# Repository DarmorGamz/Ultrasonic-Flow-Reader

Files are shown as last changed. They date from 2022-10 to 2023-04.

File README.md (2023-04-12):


<!-- PROJECT LOGO -->
<br />
<div align="center">
  <a href="https://github.com/DarmorGamz/Ultrasonic-Flow-Reader">
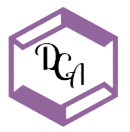
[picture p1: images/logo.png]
    
  </a>
<h3 align="center">Ultrasonic Flow Reader</h3>

  <p align="center">
    The Ultra Sonic Flow Reader is a non-invasive, innovative solution that enables real-time water flow monitoring in pipes using ultrasonic waves. Designed for homeowners, residential and industrial building owners, and property managers, this device helps reduce installation costs and risks associated with traditional inline installations, while promoting water conservation and potential cost savings.
    <br />
    <br />
    <a href="https://github.com/DarmorGamz/Ultrasonic-Flow-Reader">View Demo</a>
    ·
    <a href="https://github.com/DarmorGamz/Ultrasonic-Flow-Reader/issues">Report Bug</a>
    ·
    <a href="https://github.com/DarmorGamz/Ultrasonic-Flow-Reader/issues">Request Feature</a>
  </p>
</div>

### Built With

[][C-url]

[][HTML-url] [][CSS3-url] [][JavaScript-url]

[][PHP-url] [][MYSQL-url] [][Linux-url] [][AWS-url]

<!-- ABSTRACT -->
## ABSTRACT
The Ultra Sonic Flow Reader is a non-invasive solution designed to measure the flow of water in pipes using ultrasonic waves, eliminating the need for costly and time-consuming inline installation by licensed plumbers. Targeting homeowners, residential and industrial building owners, and property managers, this innovative device empowers users to monitor their water usage in real time, leading to potential cost savings and improved water conservation. The project employs ultrasonic transducers, a SAMD20 microcontroller, Winc1500 for WiFi, ENC28J60 for Ethernet, and leverages AWS for RDS, EC2, and Route53. The firmware is developed using Embedded C, with a PHP backend, and a frontend designed using HTML, CSS, and JavaScript. The Ultra Sonic Flow Reader is expected to minimize the need for hiring plumbers and reduce the risk of potential damage associated with traditional inline installations. The project's final demonstration is scheduled for April 13, 2023, showcasing a user-friendly and efficient solution for real-time water usage monitoring.

<!-- INTRODUCTION -->
## INTRODUCTION

#### Enhancing Water Usage Monitoring
The Ultra Sonic Flow Reader project was conceived with the primary goal of addressing a pressing need in the field of water monitoring and management. Traditional methods for measuring water flow in pipes typically require invasive installations and the assistance of licensed plumbers. This process can be both expensive and time-consuming, posing significant challenges for homeowners, residential and industrial building owners, and property managers who are looking to monitor their water usage in real time. As water scarcity becomes an increasingly critical global issue, there is a growing demand for innovative solutions that facilitate efficient water management and conservation.

#### Target Users and Applications
The project's scope encompasses the design and development of a non-invasive, cost-effective, and user-friendly device capable of real-time water usage monitoring. The Ultra Sonic Flow Reader employs advanced technologies such as ultrasonic transducers, a SAMD20 microcontroller, Winc1500 for WiFi, and ENC28J60 for Ethernet. In addition, it leverages Amazon Web Services (AWS) for database management (RDS), cloud computing (EC2), and domain name management (Route53). The device's firmware is developed using Embedded C, while the backend is built using PHP, and the frontend is designed with HTML, CSS, and JavaScript.

#### Project Development Phases
The approach taken to the project involved extensive research, planning, and execution of various design phases, including hardware and software development, integration, and testing. The interdisciplinary team, consisting of Darren Morrison, Austin Cormier, and Carter Glynn, collaborated closely under the supervision of Professors Hameed Al-Aubodah, Hamood-ur Rehman, Jane Carr, and Mehrdad Hajivandi to bring the project to fruition.

#### Challenges of Traditional Inline Installations
The Ultra Sonic Flow Reader project has been designed with a focus on simplicity, adaptability, and ease of use. Recognizing the diverse needs of homeowners, property managers, and residential and industrial building owners, the team has strived to create a solution that caters to a wide range of applications. The device's non-invasive nature ensures that it can be installed without causing disruptions to existing infrastructure or requiring specialized skills.
Throughout the project, the team has been guided by a set of core principles, including innovation, collaboration, and a commitment to addressing real-world challenges. These principles have driven the development process and informed key decisions, such as the selection of appropriate hardware components, software design, and integration strategies. Additionally, the team has placed a strong emphasis on testing and validation, ensuring that the Ultra Sonic Flow Reader consistently delivers accurate and reliable results.
As the project progresses towards its final demonstration, scheduled for April 13, 2023, the team remains dedicated to refining the Ultra Sonic Flow Reader and addressing any outstanding issues or limitations. The team acknowledges that further research and development efforts will be essential in enhancing the device's applicability to a wider range of pipe sizes and optimizing its power supply requirements. By addressing these challenges, the Ultra Sonic Flow Reader will be better positioned to meet the needs of its target users and make a positive impact on water management and conservation efforts.
In summary, the Ultra Sonic Flow Reader project represents a significant advancement in the field of water monitoring and management. By offering a non-invasive, cost-effective, and user-friendly solution for real-time water usage monitoring, the device has the potential to transform the way homeowners, building owners, and property managers approach water conservation. This report serves to document the project's journey from conception to completion, providing a comprehensive account of the team's research, development, and validation efforts.
This report details the problem statement, which outlines the challenges faced by traditional inline water flow monitoring systems and the need for a non-invasive alternative. The development process, including the project proposal, changes and decisions made throughout the project, and challenges encountered in implementation, is thoroughly discussed. Furthermore, the report presents the testing procedures and results, including Sprint tests, Product Validation tests, and an assessment of whether all user needs and requirements have been met. To support the report, relevant research materials, schematics, flowcharts, source code, and other documentation are included in the appendices.

#### Problem Statement
The Ultra Sonic Flow Reader project aims to revolutionize water monitoring by providing a solution that eliminates the need for hiring plumbers and reduces the risk of potential damage associated with traditional inline installations. By offering real-time water usage monitoring, the device empowers users to make informed decisions about their water consumption, leading to potential cost savings and improved water conservation efforts.

#### Report Structure
This report is organized into several sections, each focusing on a different aspect of the project. Following the introduction, the report details the problem statement, project development process, testing procedures and results, and any remaining limitations or challenges. The appendices provide additional documentation and materials to support the main body of the report.

<!-- INTRODUCTION -->
## DISCUSSION
The development of the Ultra Sonic Flow Reader project can be broken down into several key phases, each contributing to the overall success of the project. In this section, we discuss the progression of the project from proposal to completion, highlighting the changes and decisions made, challenges faced during implementation, and the various tests conducted.

#### Project Proposal and Initial Development
The project proposal was the foundation for the Ultra Sonic Flow Reader, outlining the primary objectives, expected outcomes, and proposed timeline. The team performed extensive research on existing flow measurement methods, identifying the limitations and drawbacks of traditional inline installations. This analysis informed the decision to pursue a non-invasive solution using ultrasonic waves for flow measurement.
Initial development focused on selecting appropriate hardware components, such as the ultrasonic transducers and SAMD20 microcontroller, and designing the basic hardware structure. The team also began work on the firmware using Embedded C and the backend using PHP, laying the groundwork for further development.

#### Iterative Development and Integration
Throughout the project, the team adopted an iterative development process, allowing for continuous improvements and adjustments. Hardware and software components were developed in parallel, with regular integration and testing to ensure compatibility and functionality.
Several changes were made during the development process, including the addition of Winc1500 for WiFi connectivity, ENC28J60 for Ethernet support, and the utilization of AWS for cloud-based services. These changes were made to enhance the device's usability and align it with modern IoT-based solutions.

#### Challenges and Implementation
The team encountered various challenges during the implementation phase. These included limited funding, time constraints, and complexities in debugging and hardware design. To overcome these challenges, the team members worked collaboratively, leveraging their individual skills and expertise to find solutions.
One of the key challenges was ensuring accurate flow measurement across various pipe sizes and materials. The team focused on refining the ultrasonic transducer placement and signal processing algorithms to achieve reliable results. Furthermore, optimizing power consumption was a priority, and the team worked on designing an energy-efficient system that minimizes the need for additional power sources.

#### Testing and Results
The Ultra Sonic Flow Reader underwent a series of tests to ensure its functionality, accuracy, and reliability. These tests included User Information Handling, API testing, Hardware Event Handling, and Hardware Timers testing. Each test was designed to evaluate specific aspects of the device's performance and identify areas for improvement.
The results of these tests showed that the Ultra Sonic Flow Reader met most user needs and requirements, delivering accurate flow measurements and a responsive user interface. However, some limitations were identified, such as the need for a more modular sensor PCB mount and optimization of the power supply.

#### References to Appendices
Throughout the report, references are made to the appendices, which contain supplementary material such as research materials, schematics, flowcharts, and source code. These documents provide a more in-depth understanding of the Ultra Sonic Flow Reader's design and development process and can be used to replicate the project and verify its results.

<!-- RECOMMENDATION -->
## RECOMMENDATION
Based on the findings and conclusions of the Ultra Sonic Flow Reader project, the following recommendations are provided to guide future research, development, and commercialization efforts.

#### Wider Pipe Size Compatibility
The current design supports only 1-inch pipes, limiting the applicability of the device. Future research should focus on developing a more modular sensor PCB mount, enabling compatibility with a broader range of pipe sizes to cater to various residential and industrial applications.

#### Power Supply Optimization
The power supply requirements of the current design demand a minimum of 12V for the sensor PCB to function. Optimizing the power supply to support lower voltage levels could enhance the device's energy efficiency, minimize the need for additional power sources, and potentially extend its battery life.

#### Enhanced User Interface
While the existing user interface is functional, it could benefit from further refinement to improve user experience. Future iterations should consider incorporating more advanced data visualization features, customizable alerts, and a mobile application for increased accessibility.

#### Market Research and Consumer Feedback
Conduct market research and solicit feedback from potential end-users to gain insights into user needs, preferences, and potential use cases. This information can inform future design decisions and contribute to the development of a more market-ready product.

#### Compliance with Regulatory Standards
As the project moves towards commercialization, it is crucial to research safety requirements, electronic stamping, and other relevant industry standards to ensure the Ultra Sonic Flow Reader complies with all necessary regulations.

#### Cost Reduction and Production Efficiency
To improve profit margins and streamline production, consider bulk purchasing of components, outsourcing board soldering, and adopting lean manufacturing practices.

#### Long-term Testing and Reliability
Further long-term testing should be conducted to assess the device's durability, performance consistency, and overall reliability under various environmental conditions and extended usage periods.
By addressing these recommendations, the Ultra Sonic Flow Reader can evolve into a more refined and market-ready product, better positioned to meet the needs of its target users and contribute significantly to water conservation efforts.

<!-- APPENDICES -->
## APPENDICES
#### Schematics
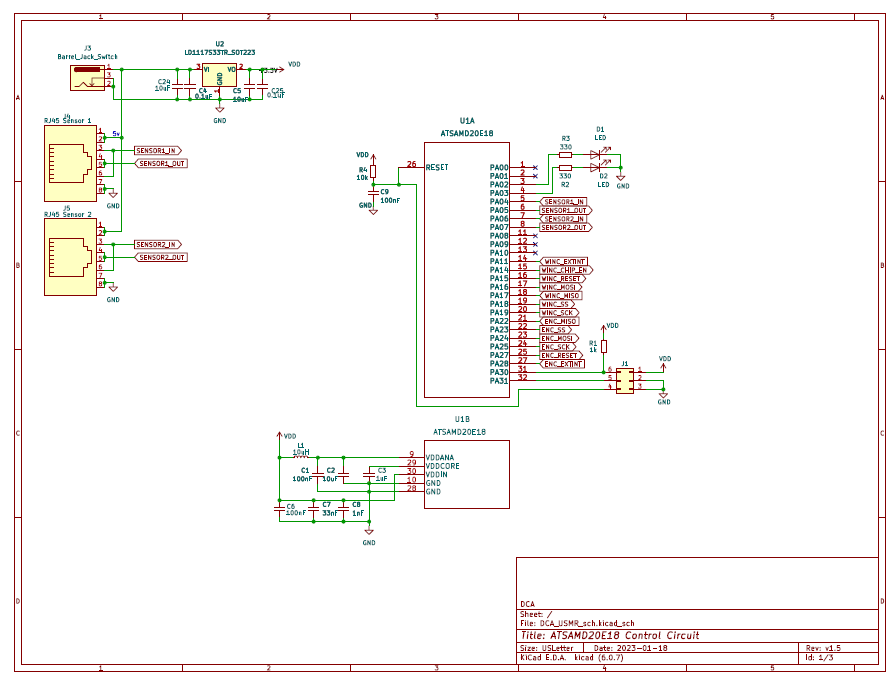
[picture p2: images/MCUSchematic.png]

Fig. 1.	MCU - Atmel SAMD20 circuit.

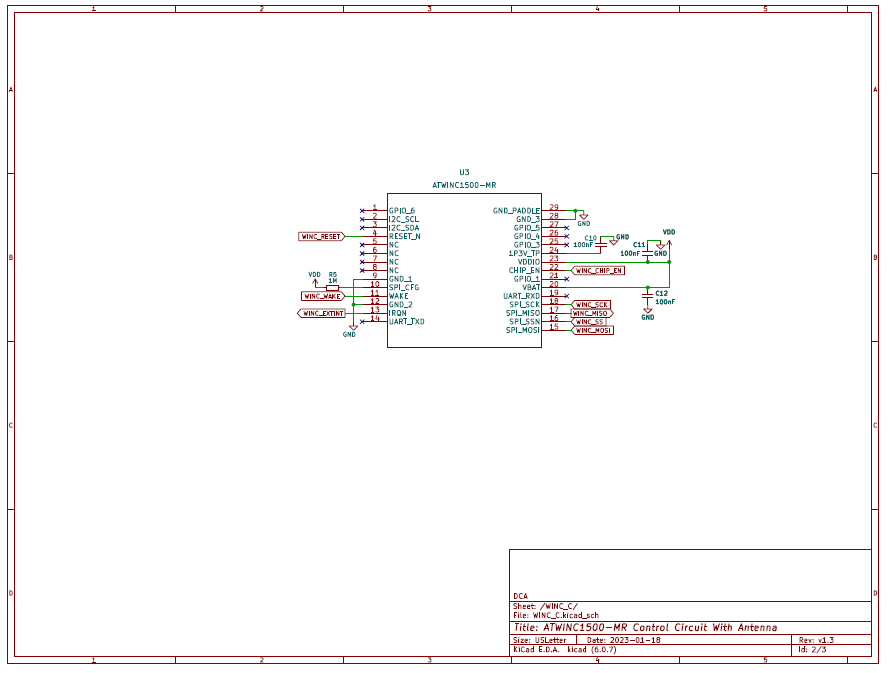
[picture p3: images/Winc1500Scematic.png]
 
Fig. 2.	Wifi – Winc1500 circuit.

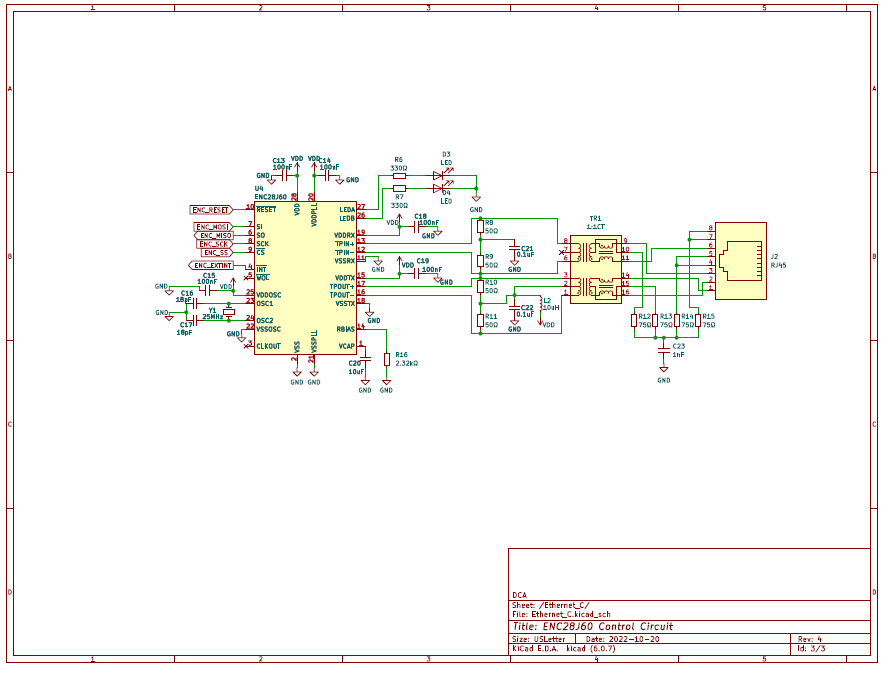
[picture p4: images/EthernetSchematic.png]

Fig. 3.	Ethernet – ENC28J60 circuit.

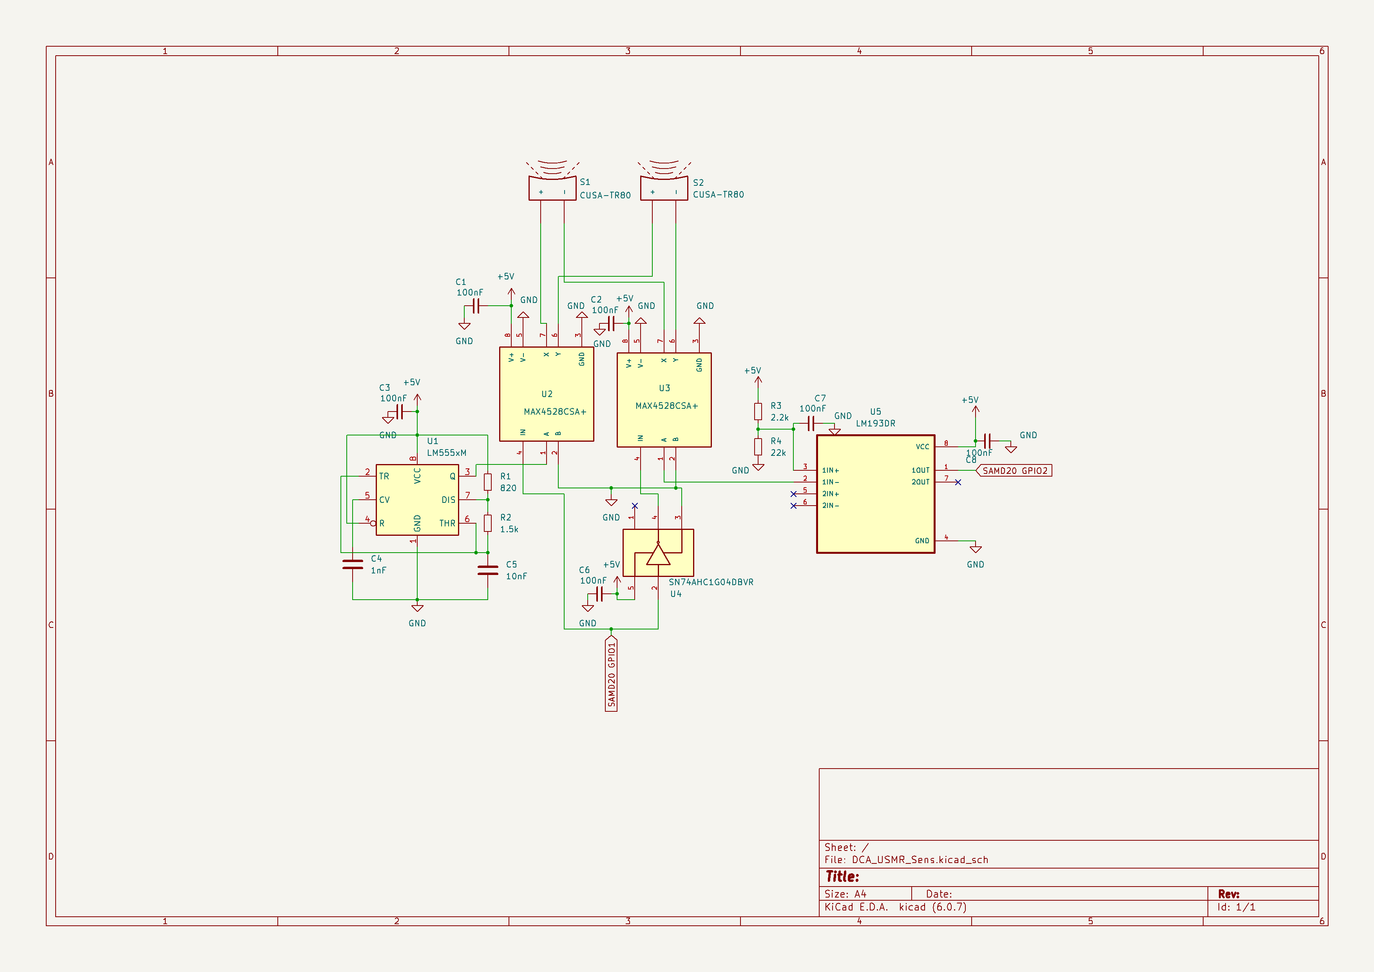
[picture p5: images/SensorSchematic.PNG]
 
Fig. 4.	Sensor – Ultra sonic flow reader circuit.   

#### Flowcharts
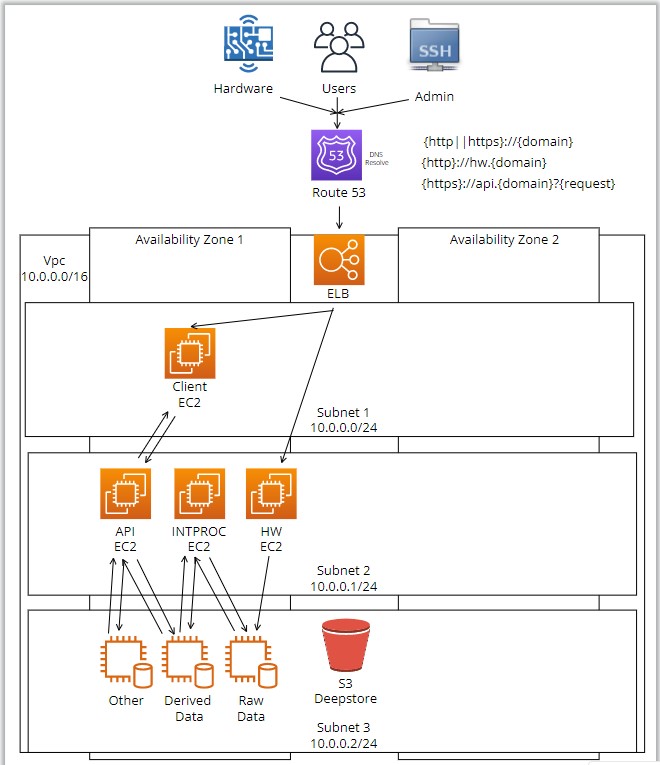
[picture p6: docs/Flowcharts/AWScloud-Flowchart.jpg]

Fig. 5. Cloud – AWS design flowchart

<!-- GETTING STARTED -->
## Getting Started

This is an example of how you may give instructions on setting up your project locally.
To get a local copy up and running follow these simple example steps.

### Prerequisites

### Installation

<p align="right">(<a href="#readme-top">back to top</a>)</p>

<!-- CONTRIBUTING -->
## Contributing

Contributions are what make the open source community such an amazing place to learn, inspire, and create. Any contributions you make are **greatly appreciated**.

If you have a suggestion that would make this better, please fork the repo and create a pull request. You can also simply open an issue with the tag "enhancement".
Don't forget to give the project a star! Thanks again!

1. Fork the Project
2. Create your Feature Branch (`git checkout -b feature/AmazingFeature`)
3. Commit your Changes (`git commit -m 'Add some AmazingFeature'`)
4. Push to the Branch (`git push origin feature/AmazingFeature`)
5. Open a Pull Request

<p align="right">(<a href="#readme-top">back to top</a>)</p>

<!-- LICENSE -->
## License

Distributed under the Eyedro Green Solutions License. See `LICENSE.txt` for more information.

<p align="right">(<a href="#readme-top">back to top</a>)</p>

<!-- CONTACT -->
## Contact

Darren Morrison - darren09@live.ca  
Austin Cormier - austin14cormier@gmail.com   
Carter Glynn - carter.glynn14@gmail.com  

Project Link: [https://github.com/DarmorGamz/Ultrasonic-Flow-Reader](https://github.com/DarmorGamz/Ultrasonic-Flow-Reader)

<p align="right">(<a href="#readme-top">back to top</a>)</p>

<!-- ACKNOWLEDGMENTS -->
## Acknowledgments
We are deeply grateful to the following individuals for their invaluable contributions, guidance, and support during the development of the Ultra Sonic Flow Reader project:   

#### Dr. Hameed Al-Aubodah, PhD
*For his expertise in electrical theory (DC, AC, Transmission lines) and digital design, and for being an inspiring role model in the engineering field.*

#### Dr. Hamood-Ur Rehman, PhD
*For sharing essential software and programming knowledge, ensuring elegant, readable, and maintainable code, and for setting high expectations that contributed to the project's success.*

#### Dr. Mehrdad Hajivandi, PhD P.Eng
*For his guidance in mathematics and advanced thinking principles crucial to the project's development.*

#### Jane Carr
*For her expertise in testing, debugging, verification, and documentation, which played a significant role in the project's completion.*   
<br />
We also extend our appreciation to Eyedro Green Solutions for their generous funding, access to lab equipment, and invaluable mentorship throughout the project. Special thanks to:   

#### Trevor Orton, CEO
*For his guidance in cloud computing, backend development, and writing and maintaining quality code.*

#### Nick Gamble, CFO
*For sharing his expertise in embedded software, embedded systems, networking, and data analysis.*

#### Jeff Conley
*For his dedication to hardware design, product specifications, circuit design, PCB assembly, and document review.*  

<p align="right">(<a href="#readme-top">back to top</a>)</p>

<!-- REFERENCES -->
## References

T. Dean, "Sonar," Brown University, [Online]. Available: https://cs.brown.edu/people/tdean/courses/cs148/02/sonar.html.  
D. Russell, "The Doppler Effect," Kettering University, [Online]. Available: https://web.archive.org/web/20071119085900/http://www.kettering.edu/~drussell/Demos/doppler/doppler.html.  
University of Bristol, "Time-of-Flight Mass Spectrometry," [Online]. Available: https://web.archive.org/web/20120310184539/http://www.chm.bris.ac.uk/ms/theory/tof-massspec.html.  
J. Steensgaard, "Bootstrapped low-voltage analog switches," in 1999 IEEE International Symposium on Circuits and Systems (ISCAS), Orlando, FL, USA, 1999, pp. 29-32, vol.2, doi: 10.1109/ISCAS.1999.780611.  
Microchip Technology Inc., "SAMD20 Family Datasheet," [Online]. Available: https://ww1.microchip.com/downloads/en/DeviceDoc/SAM_D20_Family_Datasheet_DS60001504C.pdf.  
Microchip Technology Inc., "ENC28J60 Stand-Alone Ethernet Controller with SPI Interface," [Online]. Available: https://ww1.microchip.com/downloads/aemDocuments/documents/OTH/ProductDocuments/DataSheets/39662e.pdf. 
Microchip Technology Inc., "ATWINC15x0-MR210xB IEEE 802.11 b/g/n SmartConnect IoT Module," [Online]. Available: https://ww1.microchip.com/downloads/aemDocuments/documents/WSG/ProductDocuments/DataSheets/ATWINC15x0-MR210xB-IEEE-802.11-b-g-n-SmartConnect-IoT-Module-DS70005304E.p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.  
Amazon Web Services, "Amazon EC2 User Guide," [Online]. Available: https://docs.aws.amazon.com/AWSEC2/latest/UserGuide/concepts.html.  
Amazon Web Services, "Amazon RDS User Guide," [Online]. Available: https://docs.aws.amazon.com/AmazonRDS/latest/UserGuide/Welcome.html.  

<p align="right">(<a href="#readme-top">back to top</a>)</p>

<!-- MARKDOWN LINKS & IMAGES -->
<!-- https://www.markdownguide.org/basic-syntax/#reference-style-links -->
[contributors-shield]: https://img.shields.io/github/contributors/DarmorGamz/Ultrasonic-Flow-Reader.svg?style=for-the-badge
[contributors-url]: https://github.com/DarmorGamz/Ultrasonic-Flow-Reader/graphs/contributors
[forks-shield]: https://img.shields.io/github/forks/DarmorGamz/Ultrasonic-Flow-Reader.svg?style=for-the-badge
[forks-url]: https://github.com/DarmorGamz/Ultrasonic-Flow-Reader/network/members
[stars-shield]: https://img.shields.io/github/stars/DarmorGamz/Ultrasonic-Flow-Reader.svg?style=for-the-badge
[stars-url]: https://github.com/DarmorGamz/Ultrasonic-Flow-Reader/stargazers
[issues-shield]: https://img.shields.io/github/issues/DarmorGamz/Ultrasonic-Flow-Reader.svg?style=for-the-badge
[issues-url]: https://github.com/DarmorGamz/Ultrasonic-Flow-Reader/issues
[license-shield]: https://img.shields.io/github/license/DarmorGamz/Ultrasonic-Flow-Reader.svg?style=for-the-badge
[license-url]: https://github.com/DarmorGamz/Ultrasonic-Flow-Reader/blob/master/LICENSE.txt
[linkedin-shield]: https://img.shields.io/badge/-LinkedIn-black.svg?style=for-the-badge&logo=linkedin&colorB=555
[linkedin-url]: https://linkedin.com/in/darren--morrison

[C.com]: https://img.shields.io/badge/c-%2300599C.svg?style=for-the-badge&logo=c&logoColor=white
[C-url]: https://www.cprogramming.com
[PHP.com]: https://img.shields.io/badge/php-%23777BB4.svg?style=for-the-badge&logo=php&logoColor=white
[PHP-url]: https://www.php.net/
[MYSQL.com]: https://img.shields.io/badge/mysql-%2300f.svg?style=for-the-badge&logo=mysql&logoColor=white
[MYSQL-url]: https://www.mysql.com/
[HTML.com]: https://img.shields.io/badge/html5-%23E34F26.svg?style=for-the-badge&logo=html5&logoColor=white
[HTML-url]: https://www.w3.org/html/#:~:text=W3C%20HTML&text=https%3A%2F%2Fhtml.spec.whatwg,is%20the%20current%20HTML%20standard.
[CSS3.com]: https://img.shields.io/badge/css3-%231572B6.svg?style=for-the-badge&logo=css3&logoColor=white
[CSS3-url]: https://www.css3.com/
[JavaScript.com]: https://img.shields.io/badge/javascript-%23323330.svg?style=for-the-badge&logo=javascript&logoColor=%23F7DF1E
[JavaScript-url]: https://www.javascript.com/

[Linux.com]: https://img.shields.io/badge/Linux-FCC624?style=for-the-badge&logo=linux&logoColor=black
[Linux-url]: https://aws.amazon.com/amazon-linux-2/

[AWS.com]: https://img.shields.io/badge/AWS-%23FF9900.svg?style=for-the-badge&logo=amazon-aws&logoColor=white
[AWS-url]: https://aws.amazon.com/

[PHPStorm.com]: https://img.shields.io/badge/phpstorm-143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
[PHPStorm-url]: https://www.jetbrains.com/phpstorm/

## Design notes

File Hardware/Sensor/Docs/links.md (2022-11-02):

# LINKS

## Understanding Ultrasonic Sensors
https://www.sonotec.eu/fileadmin/user_upload/business_units/1-non-invasive-fluid-monitoring/expertise/flow-meters-for-process-monitoring/wp-flow-meters-for-process-m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 

https://www.ti.com/lit/an/slaa907d/slaa907d.pdf?ts=1665290222945

https://www.maxbotix.com/articles/how-ultrasonic-sensors-work.htm

## Transducer Selection
https://www.soundwatertech.com/news/how-to-select-the-best-ultrasonic-transducer-for-your-flowmeter-application

https://www.electronics-tutorials.ws/io/io_1.html

https://webench.ti.com/webench5/TDC/index.html?origin=pf_panel&app=flowHead

## Sensor Design
https://www.nxp.com/docs/en/reference-manual/DRM138.pdf

https://www.analog.com/en/design-center/reference-designs/circuits-from-the-lab/cn0343.html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

https://media.digikey.com/pdf/Data%20Sheets/Adafruit%20PDFs/4007_Web.pdf

https://media.digikey.com/pdf/Data%20Sheets/Adafruit%20PDFs/3942_Web.pdf

https://invensense.tdk.com/wp-content/uploads/2021/01/DS-000331-CH101-v1.4.pdf

https://www.maxbotix.com/documents/LV-MaxSonar-EZ_Datasheet.pdf

https://www.youtube.com/watch?v=e_cyxoqvWe8

https://www.youtube.com/watch?v=z4uxC7ISd-c

## Signal Processing
https://starfishmedical.com/blog/pros-cons-two-popular-ultrasound-signal-processing-techniques/

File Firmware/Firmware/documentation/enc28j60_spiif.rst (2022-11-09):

Microchip ENC28J60 Ethernet Controlloer
=======================================

The ENC28J60 is a stand-alone Ethernet controller
with an industry standard Serial Peripheral Interface
(SPI). It is designed to serve as an Ethernet network
interface for any controller equipped with SPI.

The ENC28J60 meets all of the IEEE 802.3 specifications.
It incorporates a number of packet filtering
schemes to limit incoming packets. It also provides an
internal DMA module for fast data throughput and hardware
assisted checksum calculation, which is used in
various network protocols. Communication with the
host controller is implemented via an interrupt pin and
the SPI, with clock rates of up to 20 MHz. Two
dedicated pins are used for LED link and network
activity indication.

Features
--------
* An SPI interface that serves as a communication channel between the host
  controller and the ENC28J60.
* Control registers which are used to control and monitor the ENC28J60.
* A dual port RAM buffer for received and transmitted data packets.
* An arbiter to control the access to the RAM buffer when requests are made
  from DMA, transmit and receive blocks.
* The bus interface that interprets data and commands received via the SPI
  interface.
* The MAC (Medium Access Control) module that implements IEEE 802.3 compliant
  MAC logic.
* The PHY (Physical Layer) module that encodes and decodes the analog data that
  is present on the twisted-pair interface.

Support
-------
[Home]: http://www.microchip.com/ENC28J60

Knows issues and workarounds
----------------------------
Currently The AVR SPI driver will not init the MOSI and SCK pin.
The Application and Example for TCPIP Lite Stack should modified after
import project into IDE(Atmel Stdio 7 or IAR).
The workaroud is put below code into driver_init.c->system_init() function:
MOSI_set_dir(PORT_DIR_OUT);
SCK_set_dir(PORT_DIR_OUT);
The MOSI and SCK keyword in above function maybe different with projects.
Please change them according the atmel_start_pins.h

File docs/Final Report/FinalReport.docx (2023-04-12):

# Ultra Sonic Flow Reader

# Senior Capstone Final Report

# Submitted by:

Darren Morrison

Austin Cormier

Carter Glynn

CET/EET Third Year

Under the Mentorship of

Dr. Hameed Al-Aubodah, PhD.

Program Coordinator

Dr. Hamood-Ur Rehman, PhD

Professor

Dr. Mehrdad Hajivandi, PhD, P.Eng.

Professor

Jane Carr

Professor

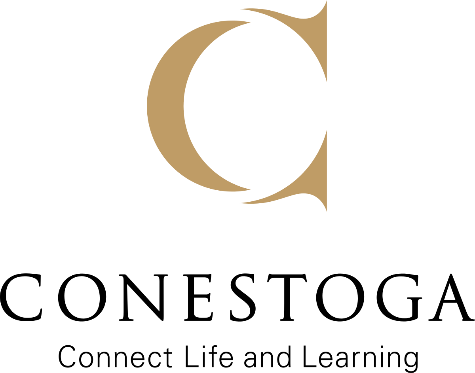
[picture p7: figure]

Computer Engineering Technology Department

Conestoga College Institute of Engineering & Technology, Cambridge

April, 2023

Ultra Sonic Flow Reader

Darren Morrison, Austin Cormier, Carter Glynn
Dept. Engineering and Technology
Conestoga College
Cambridge, Canada

Abstract—The Ultra Sonic Flow Reader is a non-invasive solution designed to measure the flow of water in pipes using ultrasonic waves, eliminating the need for costly and time-consuming inline installation by licensed plumbers. Targeting homeowners, residential and industrial building owners, and property managers, this innovative device empowers users to monitor their water usage in real time, leading to potential cost savings and improved water conservation. The project employs ultrasonic transducers, a SAMD20 microcontroller, Winc1500 for WiFi, ENC28J60 for Ethernet, and leverages AWS for RDS, EC2, and Route53. The firmware is developed using Embedded C, with a PHP backend, and a frontend designed using HTML, CSS, and JavaScript. The Ultra Sonic Flow Reader is expected to minimize the need for hiring plumbers and reduce the risk of potential damage associated with traditional inline installations. The project's final demonstration is scheduled for April 13, 2023, showcasing a user-friendly and efficient solution for real-time water usage monitoring.

Keywords—Ultrasonic flow measurement, Non-invasive flow monitoring, Water conservation, Real-time water usage, Internet of Things (IoT), Smart water management

##### Table of Contents

A) Enhancing Water Usage Monitoring
B) Target Users and Applications
C) Project Development Phases
D) Challenges of Traditional Inline Installations
E) Problem Statement
F) Report Structure
A) Project Proposal and Initial Development
B) Iterative Development and Integration
C) Challenges and Implementation
D) Testing and Results
E) References to Appendices
1. CONCLUSIONS
2. RECOMMENDATIONS
A) Wider Pipe Size Compatibility
B) Power Supply Optimization
C) Enhanced User Interface
D) Market Research and Consumer Feedback
E) Compliance with Regulatory Standards
F) Cost Reduction and Production Efficiency
G) Long-term Testing and Reliability
3. APPENDICES
A) SCHEMATICS

Fig 1) MCU - Atmel SAMD20 circuit

Fig 2) Wi-Fi – Winc1500 circuit

Fig 3) Ethernet – ENC28J60 circuit

Fig 4) Sensor – Ultra sonic flow reader circuit

B) FLOWCHARTS

Fig 5) Cloud – AWS design flowchart

Fig 6) Hardware – MCU component block diagram

Fig 7) Firmware – Embedded logic loop

Fig 8) Firmware - Embedded Clock Initialization

Fig 9) Firmware – Embedded Peripheral Initialization

4. ACKNOWLEDGMENTS
5. REFERENCES

# 1. Introduction

## A. Enhancing Water Usage Monitoring

The Ultra Sonic Flow Reader project was conceived with the primary goal of addressing a pressing need in the field of water monitoring and management. Traditional methods for measuring water flow in pipes typically require invasive installations and the assistance of licensed plumbers. This process can be both expensive and time-consuming, posing significant challenges for homeowners, residential and industrial building owners, and property managers who are looking to monitor their water usage in real time. As water scarcity becomes an increasingly critical global issue, there is a growing demand for innovative solutions that facilitate efficient water management and conservation.

## B. Target Users and Applications

The project's scope encompasses the design and development of a non-invasive, cost-effective, and user-friendly device capable of real-time water usage monitoring. The Ultra Sonic Flow Reader employs advanced technologies such as ultrasonic transducers, a SAMD20 microcontroller, Winc1500 for WiFi, and ENC28J60 for Ethernet. In addition, it leverages Amazon Web Services (AWS) for database management (RDS), cloud computing (EC2), and domain name management (Route53). The device's firmware is developed using Embedded C, while the backend is built using PHP, and the frontend is designed with HTML, CSS, and JavaScript.

## C. Project Development Phases

The approach taken to the project involved extensive research, planning, and execution of various design phases, including hardware and software development, integration, and testing. The interdisciplinary team, consisting of Darren Morrison, Austin Cormier, and Carter Glynn, collaborated closely under the supervision of Professors Hameed Al-Aubodah, Hamood-ur Rehman, Jane Carr, and Mehrdad Hajivandi to bring the project to fruition.

## D. Challenges of Traditional Inline Installations

The Ultra Sonic Flow Reader project has been designed with a focus on simplicity, adaptability, and ease of use. Recognizing the diverse needs of homeowners, property managers, and residential and industrial building owners, the team has strived to create a solution that caters to a wide range of applications. The device's non-invasive nature ensures that it can be installed without causing disruptions to existing infrastructure or requiring specialized skills.

Throughout the project, the team has been guided by a set of core principles, including innovation, collaboration, and a commitment to addressing real-world challenges. These principles have driven the development process and informed key decisions, such as the selection of appropriate hardware components, software design, and integration strategies. Additionally, the team has placed a strong emphasis on testing and validation, ensuring that the Ultra Sonic Flow Reader consistently delivers accurate and reliable results.

As the project progresses towards its final demonstration, scheduled for April 13, 2023, the team remains dedicated to refining the Ultra Sonic Flow Reader and addressing any outstanding issues or limitations. The team acknowledges that further research and development efforts will be essential in enhancing the device's applicability to a wider range of pipe sizes and optimizing its power supply requirements. By addressing these challenges, the Ultra Sonic Flow Reader will be better positioned to meet the needs of its target users and make a positive impact on water management and conservation efforts.

In summary, the Ultra Sonic Flow Reader project represents a significant advancement in the field of water monitoring and management. By offering a non-invasive, cost-effective, and user-friendly solution for real-time water usage monitoring, the device has the potential to transform the way homeowners, building owners, and property managers approach water conservation. This report serves to document the project's journey from conception to completion, providing a comprehensive account of the team's research, development, and validation efforts.

This report details the problem statement, which outlines the challenges faced by traditional inline water flow monitoring systems and the need for a non-invasive alternative. The development process, including the project proposal, changes and decisions made throughout the project, and challenges encountered in implementation, is thoroughly discussed. Furthermore, the report presents the testing procedures and results, including Sprint tests, Product Validation tests, and an assessment of whether all user needs and requirements have been met. To support the report, relevant research materials, schematics, flowcharts, source code, and other documentation are included in the appendices.

## E. Problem Statement

The Ultra Sonic Flow Reader project aims to revolutionize water monitoring by providing a solution that eliminates the need for hiring plumbers and reduces the risk of potential damage associated with traditional inline installations. By offering real-time water usage monitoring, the device empowers users to make informed decisions about their water consumption, leading to potential cost savings and improved water conservation efforts.

## F. Report Structure

This report is organized into several sections, each focusing on a different aspect of the project. Following the introduction, the report details the problem statement, project development process, testing procedures and results, and any remaining limitations or challenges. The appendices provide additional documentation and materials to support the main body of the report.

# 2. Discussion

The development of the Ultra Sonic Flow Reader project can be broken down into several key phases, each contributing to the overall success of the project. In this section, we discuss the progression of the project from proposal to completion, highlighting the changes and decisions made, challenges faced during implementation, and the various tests conducted.

## A. Project Proposal and Initial Development

The project proposal was the foundation for the Ultra Sonic Flow Reader, outlining the primary objectives, expected outcomes, and proposed timeline. The team performed extensive research on existing flow measurement methods, identifying the limitations and drawbacks of traditional inline installations. This analysis informed the decision to pursue a non-invasive solution using ultrasonic waves for flow measurement.

Initial development focused on selecting appropriate hardware components, such as the ultrasonic transducers and SAMD20 microcontroller, and designing the basic hardware structure. The team also began work on the firmware using Embedded C and the backend using PHP, laying the groundwork for further development.

## B. Iterative Development and Integration

Throughout the project, the team adopted an iterative development process, allowing for continuous improvements and adjustments. Hardware and software components were developed in parallel, with regular integration and testing to ensure compatibility and functionality.

Several changes were made during the development process, including the addition of Winc1500 for WiFi connectivity, ENC28J60 for Ethernet support, and the utilization of AWS for cloud-based services. These changes were made to enhance the device's usability and align it with modern IoT-based solutions.

## C. Challenges and Implementation

The team encountered various challenges during the implementation phase. These included limited funding, time constraints, and complexities in debugging and hardware design. To overcome these challenges, the team members worked collaboratively, leveraging their individual skills and expertise to find solutions.

One of the key challenges was ensuring accurate flow measurement across various pipe sizes and materials. The team focused on refining the ultrasonic transducer placement and signal processing algorithms to achieve reliable results. Furthermore, optimizing power consumption was a priority, and the team worked on designing an energy-efficient system that minimizes the need for additional power sources.

## D. Testing and Results

The Ultra Sonic Flow Reader underwent a series of tests to ensure its functionality, accuracy, and reliability. These tests included User Information Handling, API testing, Hardware Event Handling, and Hardware Timers testing. Each test was designed to evaluate specific aspects of the device's performance and identify areas for improvement.

The results of these tests showed that the Ultra Sonic Flow Reader met most user needs and requirements, delivering accurate flow measurements and a responsive user interface. However, some limitations were identified, such as the need for a more modular sensor PCB mount and optimization of the power supply.

## E. References to Appendices

Throughout the report, references are made to the appendices, which contain supplementary material such as research materials, schematics, flowcharts, and source code. These documents provide a more in-depth understanding of the Ultra Sonic Flow Reader's design and development process and can be used to replicate the project and verify its results.

# 3. Conclussions

The Ultra Sonic Flow Reader project has successfully demonstrated its potential as a non-invasive, cost-effective, and user-friendly solution for real-time water usage monitoring in residential and industrial settings. By utilizing cutting-edge technologies, such as ultrasonic transducers, SAMD20 microcontroller, and cloud-based services, the team has developed a reliable and efficient system capable of addressing the challenges associated with traditional inline installations.

Throughout the development process, the team faced various obstacles, including limited funding, time constraints, and complexities in debugging and hardware design. Despite these challenges, the team members were able to work collaboratively and leverage their individual skills to exceed the expected work hours and successfully deliver a working prototype.

The testing and validation phase provided valuable insights into the Ultra Sonic Flow Reader's performance, revealing that the device met the majority of user needs and requirements. However, certain limitations were identified, such as the need for a more modular sensor PCB mount and optimization of the power supply. Addressing these limitations in future research will be crucial in enhancing the device's applicability to a wider range of pipe sizes and further optimizing its performance.

As the project moves towards potential commercialization, considerations should be made for bulk purchasing of components, outsourcing board soldering, and ensuring compliance with safety requirements and electronic stamping regulations. By addressing these aspects, the Ultra Sonic Flow Reader will be better positioned for wider market adoption and increased impact on water management and conservation efforts.

In conclusion, the Ultra Sonic Flow Reader has showcased a promising solution for real-time water usage monitoring, with the potential to lead to substantial cost savings and improved water conservation for homeowners, building owners, and property managers. Further research and development efforts will be essential in refining the product and overcoming the existing limitations, ultimately paving the way for a more sustainable and efficient approach to water management.

# 4. Recommendations

Based on the findings and conclusions of the Ultra Sonic Flow Reader project, the following recommendations are provided to guide future research, development, and commercialization efforts

## A. Wider Pipe Size Compatibility

The current design supports only 1-inch pipes, limiting the applicability of the device. Future research should focus on developing a more modular sensor PCB mount, enabling compatibility with a broader range of pipe sizes to cater to various residential and industrial applications.

## B. Power Supply Optimization

The power supply requirements of the current design demand a minimum of 12V for the sensor PCB to function. Optimizing the power supply to support lower voltage levels could enhance the device's energy efficiency, minimize the need for additional power sources, and potentially extend its battery life.

## C. Enhanced User Interface

While the existing user interface is functional, it could benefit from further refinement to improve user experience. Future iterations should consider incorporating more advanced data visualization features, customizable alerts, and a mobile application for increased accessibility.

## D. Market Research and Consumer Feedback

Conduct market research and solicit feedback from potential end-users to gain insights into user needs, preferences, and potential use cases. This information can inform future design decisions and contribute to the development of a more market-ready product.

## E. Compliance with Regulatory Standards

As the project moves towards commercialization, it is crucial to research safety requirements, electronic stamping, and other relevant industry standards to ensure the Ultra Sonic Flow Reader complies with all necessary regulations.

## F. Cost Reduction and Production Efficiency

To improve profit margins and streamline production, consider bulk purchasing of components, outsourcing board soldering, and adopting lean manufacturing practices.

## G. Long-term Testing and Reliability

Further long-term testing should be conducted to assess the device's durability, performance consistency, and overall reliability under various environmental conditions and extended usage periods.

By addressing these recommendations, the Ultra Sonic Flow Reader can evolve into a more refined and market-ready product, better positioned to meet the needs of its target users and contribute significantly to water conservation efforts.

# 5. Appendices

## A. Schematics


Fig. 1. MCU - Atmel SAMD20 circuit


Fig. 2. Wifi – Winc1500 circuit


Fig. 3. Ethernet – ENC28J60 circuit

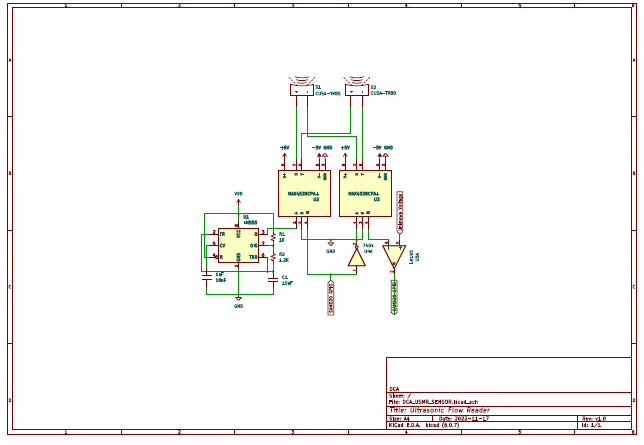
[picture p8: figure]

Fig. 4. Sensor – Ultra sonic flow reader circuit

## B. Flowcharts


Fig. 5. Cloud – AWS design flowchart

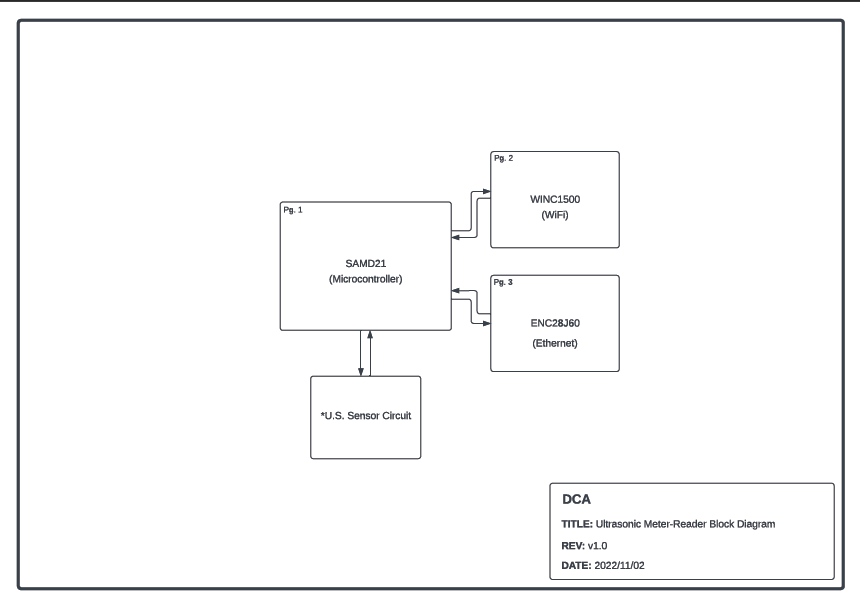
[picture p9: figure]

Fig. 6. Hardware – MCU component block diagram

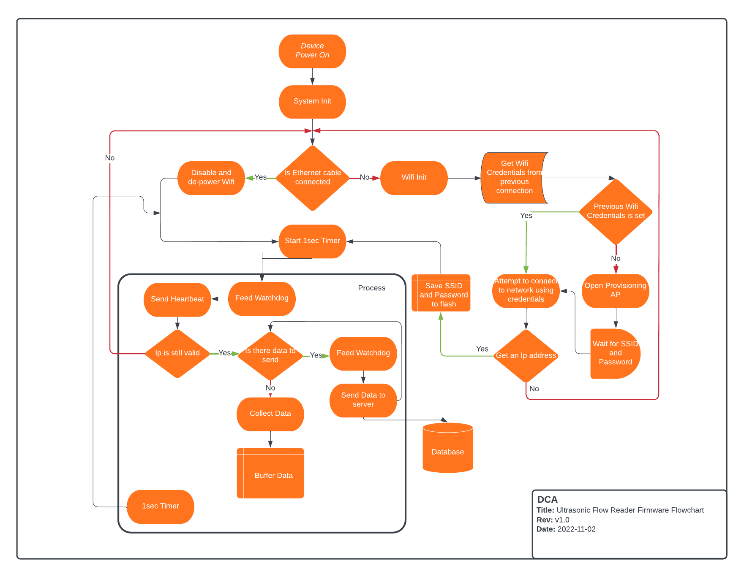
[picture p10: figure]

Fig. 7. Firmware – Embedded logic loop

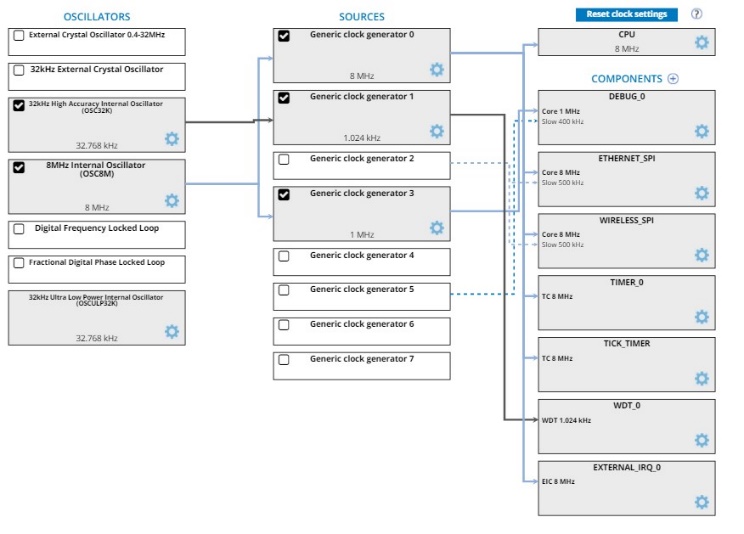
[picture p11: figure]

Fig. 8. Firmware - Embedded Clock Initialization

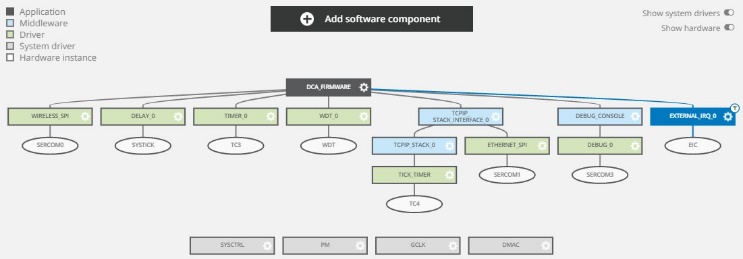
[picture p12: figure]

Fig. 9. Firmware – Embedded Peripheral Initialization

# 6. Acknowledgments

We would like to express my heartfelt gratitude to the following individuals for their invaluable contributions, guidance, and support throughout the development of the Ultra Sonic Flow Reader project:

Dr. Hameed Al-Aubodah, PhD, Program Coordinator, for providing the necessary knowledge in electrical theory (DC, AC, Transmission lines) and digital design, and for being a highly respected role model in the field of engineering.

Dr. Hamood-Ur Rehman for imparting essential knowledge in software and programming, ensuring the production of elegant, readable, and maintainable code, and for setting high expectations that contributed to the project's success.

Dr. Mehrdad Hajivandi for his guidance in mathematics and advanced thinking principles that were crucial in the project's development.

Jane Carr for her expertise in testing, debugging, verification, and documentation, which played a significant role in the project's completion.

We would also like to extend my appreciation to Eyedro Green Solutions for their generous funding, access to lab equipment, and invaluable mentorship throughout the project. Special thanks to Trevor Orton, CEO, for his guidance in cloud computing, backend development, and writing and maintaining quality code; Nick Gamble, CFO, for sharing his expertise in embedded software, embedded systems, networking, and data analysis; and Jeff Conley, for his dedication to hardware design, product specifications, circuit design, PCB assembly, and document review.

Thank you all for your invaluable contributions to this project. Your expertise, guidance, and support have been instrumental in the successful development and completion of the Ultra Sonic Flow Reader.

# 7. References

[1] [1] T. Dean, "Sonar," Brown University, [Online]. Available: https://cs.brown.edu/people/tdean/courses/cs148/02/sonar.html. [Accessed Month Day, Year].
[2] D. Russell, "The Doppler Effect," Kettering University, [Online]. Available: https://web.archive.org/web/20071119085900/http://www.kettering.edu/~drussell/Demos/doppler/doppler.html. [Accessed Month Day, Year].
[3] University of Bristol, "Time-of-Flight Mass Spectrometry," [Online]. Available: https://web.archive.org/web/20120310184539/http://www.chm.bris.ac.uk/ms/theory/tof-massspec.html. [Accessed Month Day, Year].
[4] [4] J. Steensgaard, "Bootstrapped low-voltage analog switches," in 1999 IEEE International Symposium on Circuits and Systems (ISCAS), Orlando, FL, USA, 1999, pp. 29-32, vol.2, doi: 10.1109/ISCAS.1999.780611.

[5] Microchip Technology Inc., "SAMD20 Family Datasheet," [Online]. Available: https://ww1.microchip.com/downloads/en/DeviceDoc/SAM_D20_Family_Datasheet_DS60001504C.pdf. [Accessed Month Day, Year].

[6] Microchip Technology Inc., "ENC28J60 Stand-Alone Ethernet Controller with SPI Interface," [Online]. Available: https://ww1.microchip.com/downloads/aemDocuments/documents/OTH/ProductDocuments/DataSheets/39662e.pdf. [Accessed Month Day, Year].

[7] Microchip Technology Inc., "ATWINC15x0-MR210xB IEEE 802.11 b/g/n SmartConnect IoT Module," [Online]. Available: https://ww1.microchip.com/downloads/aemDocuments/documents/WSG/ProductDocuments/DataSheets/ATWINC15x0-MR210xB-IEEE-802.11-b-g-n-SmartConnect-IoT-Module-DS70005304E.p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. [Accessed Month Day, Year].

[8] Amazon Web Services, "Amazon EC2 User Guide," [Online]. Available: https://docs.aws.amazon.com/AWSEC2/latest/UserGuide/concepts.html. [Accessed Month Day, Year].

[9] Amazon Web Services, "Amazon RDS User Guide," [Online]. Available: https://docs.aws.amazon.com/AmazonRDS/latest/UserGuide/Welcome.html. [Accessed Month Day, Year].

XXX-X-XXXX-XXXX-X/XX/$XX.00 ©2023 IEEE

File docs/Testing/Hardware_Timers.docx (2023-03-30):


DCA Testing

Hardware Clocks & Timers

2023-03-22

Table of Contents

1.0 Purpose……………………………………………………………………………………………………………………………… 2
2.0 Overview……………………………………………………………………………………………………………………………. 2
3.0 Scope…………………………………………………………………………………………………………………………………. x
  3.1 SYSTICK ……………………………………………………………………………………………….………… x
  3.2 RTC ……………………………………………………………………………………..………………..…..…. x
  3.3 TICK TIMER ………………………………………………………………………………………………..…. x
  3.4 SAMPLE TIMER……………………………………………………………………………………………... x
  3.5 WDT TIMER ………………………………………………………………………………………………….. x
4.0 Results………………………………………………………………………………………………………………………………. x
5.0 Analysis……………………………………………………………………………………………………………………………… x
1.0 Purpose

The internal core clock frequency used on the hardware module is 8Mhz, while a second high precision 32kHz clock is also used for timers. The 32bit timer (RTC) is running at 8Mhz, the 16bit Tick Timer used by the TCPIP stack is running at high precision 32kHz, the 32bit Sample timer used by the sensor interrupt for tick count is running at 8Mhz, the 16bit timer used by the WDT is running at high precision 32Khz.

2.0 Overview

The accuracy and drift of each timer is an important issue due to the time sensitivity of each task or event attached. RTC handles the timestamps used for data, events, and time synchronization. Tick Timer is used for the TCPIP send and receive. Tick Timer is also piggy backed for a 1sec callback event. The Sample timer is the fastested timer used. This is not used for a timestamp, but is used for delta time difference in ticks. This converts to nanosecond speeds. The WDT timer is not as important for accuracy, however the functionality of the WDT is important to prevent a customers hardware from going into a fail state indefinitely.

- Screenshots/pictures
3.0 Scope

The entirety of the API endpoints will be tested. Each endpoint for data, and user functionality will be tested through the browser/POST. All of these endpoints will be tested rigorously.

3.1 SYSTICK

The 24bit, SYSTICK timer running at 8MHz is not used in our application explicitly. Any background stacks using this are not doing any time sensitive work. This won’t be tested.

3.2 RTC

The RTC is a 32bit timer, running at 8Mhz/8=1Mhz. Each full count of the RTC equals 1second. An interrupt function is attached to this count timer, which increments the stored time() value inside the embedded system. This is used for time synchronization between the server and hardware.

Every test after this one will rely on the accuracy of this timer as it’s used to write to debug with a timestamp. Any event or data sent to server uses this value.

The tests for this timer will to ensure the Set_Timestamp(), and GetTimestamp() are not returning errors, and the results are expected. These expected results are setting the timestamp with a known value (from server) and an immediate call of Get_Timestamp() will reflect the value. This RTC value is read from the Count register.

3.3 TICK TIMER

The tick timer is running at 32kHz high precision. This is used explicitly by the TCPIP stack async functionality. This timer is also piggy backed at a 1sec interrupt to perform data calculation, status led code presentation, and timer pumps.

The test for this relies on the previous timer (RTC)’s accuracy. The test for this will be to debug store in memory a timestamp every interrupt. This test will occur over 1 hour periods as a heartbeat re-sync event in the case of no data recorded is called every hour. This will test the drift over an hour period as this is the longest it will possibly go without a resync.

3.4 SAMPLE TIMER

This timer is used to measure the delta difference between each sensor interrupt to calculate average. While this timer is used to read TICKS, the timer is ran at 8Mhz with no prescaler. The fastest speed this timer can run is 125ns. While this timer is 32bit, it will be reset every second to ensure the average over a 1sec period never has a register count roll over causing inaccuracy. The test for this will be to debug store the current ticks at the 1sec interrupt, reset the count register, and read it back ensuring it’s zero. This timer is so quick, it will be difficult to internally test it without an external clock source.

3.5 WDT

This timer is used to prevent a customer’s hardware from going into an unexpected state, indefinitely. Every iteration of the main loop, the watchdog is fed. This timer runs using the 32kHz high precision timer, and is prescaled to run at 1sec intervals. The WDT peripheral is initialized to reset the hardware after 8 seconds without being fed.

The test for this is to take the timestamp before the watchdog timer is started, commenting out the watchdog feed, and comparing the reset timestamp. This difference should be approx (8*3600)ms. The accuracy of this isn’t highly important as it’s reset many times a second, however the deviation shouldn’t be more than +-3600ms

4.0 Results

Number of Test Cases Planned | Number of Test Cases Executed | Number of Tests Cases Passed | Number of Test Cases Failed
12 | 12 | 12 | 0

Tests were carried out for each scope one at a time, three times each, for a total of 18 test cases.

5.0 Analysis

All test cases were passed without issue. Every timer ran as expected with little to no drift when sync’d with server. The drift on the on the RTC with 1 hour between re-syncs was less than 1000ms (1second). This accuracy is enough to ensure data sent to the server is on the correct x-bound timestamps.

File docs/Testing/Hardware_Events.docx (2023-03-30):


DCA Testing

Hardware Events

2023-03-22

Table of Contents

1.0 Purpose……………………………………………………………………………………………………………………………… 2
2.0 Overview……………………………………………………………………………………………………………………………. 2
3.0 Scope…………………………………………………………………………………………………………………………………. x
  3.1 Startup……………………………………………………………………………………………………… x
  3.2 Time Sync…………………………………………………………………………………………………. x
  3.3 Reset Cause ………………………………………………………………………………………….…. x
  3.4 Errors …………………………………………………………………………………………………….... x
4.0 Results………………………………………………………………………………………………………………………………. x
5.0 Analysis……………………………………………………………………………………………………………………………… x
1.0 Purpose

Event handling inside the hardware is important to ensure expected results are occurring. Without the logging of events, there would be no way for an Admin, Dev, User or the server from knowing what the device is doing without shelling in. Without events, there’s only guess and hoping that expected results are occurring.

2.0 Overview

The event handling inside the hardware is modular and allows easy adding and removing of new and old events. While more events will be added in the future such as getvar, setvar etc.. only a basic skeleton currently is available. Current available events are Startup, Time Sync, Reset Cause, and Errors.

- Screenshots/pictures
3.0 Scope

The entirety of the event class will be tested. Each event will be massaged to run so the logging of the event occurs.

3.1 Startup

This event occurs anytime the device powers up or is restarted either forcible or accidentally.

To cause this event to occur, the hardware module will be manually unplugged, and re plugged to power. This will be done at the wall, and not the hardware module itself to prevent exhaustion of the DC Barrel.

3.2 Time Sync

This event occurs ONLY after another event is already sent to the server. A timestamp is always returned from a CmdSend to the server. On recv, if the time differs more than 3 seconds, the hardware will updated it’s internal clock, and send a Time Sync event.

To have this occur, a delay can be injected into each main loop iteration to cross the 3sec resync delay. Another method to make this occur is to unplug the device for a set period of time, once reconnected a startup event will occur, and a Time Sync event will piggyback.

3.3 Reset Cause

The current reset causes available are WDT reset, Brown out 1.8V reset, and Brown out 1.2V Brown out reset.

A method to for this to occur is to make the main loop delay longer than the WDT timeout (8sec). Another method is to temp comment out the WDT Feed function.

3.4 Error

This event occurs when any unexpected errors occur. This can appear as an initialization issue, a return issue, a type cast issue etc.

In an ideal world, this never happens. However, the event is captured and transmitted to the device log to help debug issues. To manually cause an error to occur, I can transmit an unexpected response from the server to cause the device to log an error.

4.0 Results

Number of Test Cases Planned | Number of Test Cases Executed | Number of Tests Cases Passed | Number of Test Cases Failed
18 | 18 | 18 | 0

Tests were carried out for each scope one at a time, three times each, for a total of 18 test cases.

5.0 Analysis

All test cases were passed without issue. Every endpoint returned an expected value and was repeatable. This ensures the user’s experience is as expected every time.

*There’s an intermitted issue where the memory maps on the embedded system are not initialized as expected. If a large number of events occur, the EventLogBuffer in memory is stored in the wrong location and is sometimes smaller than expected, or overridden. This isn’t an issue in an environment with a solid internet connection, if the connection starts to slow down and the buffer increases in size without sending logs, It acts as a FIFO and first items will be lost.

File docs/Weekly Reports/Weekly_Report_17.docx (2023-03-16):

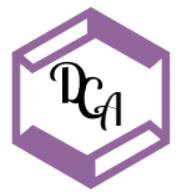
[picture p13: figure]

Ultra-Sonic Meter Reader

TEAM MEMBERS: Darren, Austin, Carter

REPORT NUMBER: Report 17

REPORT DATE: 2023-03-16

REPORT AUTHOR: Carter Glynn

THIS WEEK’S TASKS:

T84 – Test and verify comparator

T85 – Determine most efficient way to sample data with sensor circuit

T86 – Output readable highs and lows from comparator using desired input wave

T91 – Process comparator data into meaningful information on website

T93 – Adapt enclosure

PROGRESS THIS WEEK:

84 – Test and verify comparator Austin Done

85 – Determine most efficient way to sample data with sensor circuit All Done

86 – Refine readable highs and lows from comparator using desired input wave All 50%

91 – Process comparator data into meaningful information on website Darren 75%

93 – Adapt enclosure Austin 50%

NEXT WEEK’S TASKS:

T86 – Output readable highs and lows from comparator using desired input wave

T87 – Test sensors to see initial wave received after microcontroller switching

T88 – Refine microcontroller receive timing

T89 – Refine switching time and mechanics

T91 – Process comparator data into meaningful information on website

T92 – Make data visually informative and appealing on website

T93 – Adapt enclosure

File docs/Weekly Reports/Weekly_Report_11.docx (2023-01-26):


Ultra-Sonic Meter Reader

TEAM MEMBERS: Darren, Austin, Carter

REPORT NUMBER: Report 11

REPORT DATE: 2023-01-26

REPORT AUTHOR: Carter Glynn

THIS WEEK’S TASKS:

T66 - Build final sensor(s)

T69 - Design final pcb layout

T70 - Build Pcb (Sensor)

T74 - Design basic html/css layout of client

T77 - Create block diagram for sensor module connecting to MCU module

PROGRESS THIS WEEK:

T67 - Build sensor(s) reading circuit on hardware prototype

T69 - Design final pcb layout

T73 - Setup Server, database and Ide Enviroment

T75 - Communicate with backend, accept post data, store data

T83 - Create Pcb design for sensor module

T87 - Verify Ethernet module work on beta pcb MCU module

NEXT WEEK’S TASKS:

T71 - Design plastic enclosure

T72 - Order enclosure

T74 - Design basic html/css layout of client

T75 - Communicate with backend, accept post data, store data

T76 - Present 'realtime' data to the server

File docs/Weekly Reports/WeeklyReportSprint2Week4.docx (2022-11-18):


Ultra-Sonic Meter Reader

TEAM MEMBERS: Darren, Austin, Carter

REPORT NUMBER: Report 7

REPORT DATE: 2022-11-17

REPORT AUTHOR: Carter Glynn

THIS WEEK’S TASKS:

T60 – Darren, Get an IP address with Ethernet Chip attached to dev-board

T61 – Darren, On MCU powerup, determine to use Ethernet or Wi-Fi depending on if a network cable is connected to module

T44 – Austin, Create beta PCB design for MCU module

T45 – Verify PCB design for MCU module with sponsor

T31 - Create Block diagram for sensor module

T35 – Carter, Create Schematic for sensor module circuit

PROGRESS THIS WEEK:

T60 – Darren, Get an IP address with Ethernet Chip attached to dev-board

T61 – Darren, On MCU powerup, determine to use Ethernet or Wi-Fi depending on if a network cable is connected to module

T44 – Austin, Create beta PCB design for MCU module

T45 – Verify PCB design for MCU module with sponsor

T31 – Carter, Create Block diagram for sensor module

T32 - Breadboard sensor module circuit

T34 - Determine how MCU can send required frequency, do we need an oscillator or transistor to boost frequnecy from two sources?

T35 - Create Schematic for sensor module circuit

NEXT WEEK’S TASKS:

T60 – Darren, Get an IP address with Ethernet Chip attached to dev-board

T61 – Darren, On MCU powerup, determine to use Ethernet or Wi-Fi depending on if a network cable is connected to module

T46 – Austin, Build 2-3 sets of beta pcb MCU modules

T50 - Create block diagram for sensor module connecting to MCU module

T36 – Verify Schematic for sensor module with sponsor

T37 - Create Pcb design for sensor module

T38 - Build beta sensor module

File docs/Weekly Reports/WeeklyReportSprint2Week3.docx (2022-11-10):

Ultra-Sonic Meter Reader

TEAM MEMBERS: Darren, Austin, Carter

REPORT NUMBER: Report 6

REPORT DATE: 2022-11-10

REPORT AUTHOR: Darren Morrison

THIS WEEK’S TASKS:

T60 – Darren, Get an IP address with Ethernet Chip attached to dev-board

T61 – Darren, On MCU powerup, determine to use Ethernet or Wi-Fi depending on if a network cable is connected to module

T44 – Austin, Create beta PCB design for MCU module

T45 – Verify PCB design for MCU module with sponsor

T35 – Carter, Create Schematic for sensor module circuit

T36 – Carter, Verify Schematic for sensor with sponsor

PROGRESS THIS WEEK:

T59 – Darren, Interface dev-board with Ethernet Chip

T62 – Darren, enable watchdog to reset module if MCU module gets stuck in an infinite loop

T44 – Austin, Create beta PCB design for MCU module

T34 – Carter, Determine how MCU can send required frequency, do we need an oscillator or transistor to boost frequency from two sources?

NEXT WEEK’S TASKS:

T61 – Darren, On MCU powerup, determine to use Ethernet or Wi-Fi depending on if a network cable is connected to module

T46 – Austin, Build 2-3 sets of beta pcb MCU modules

T32 – Carter, Breadboard sensor module circuit

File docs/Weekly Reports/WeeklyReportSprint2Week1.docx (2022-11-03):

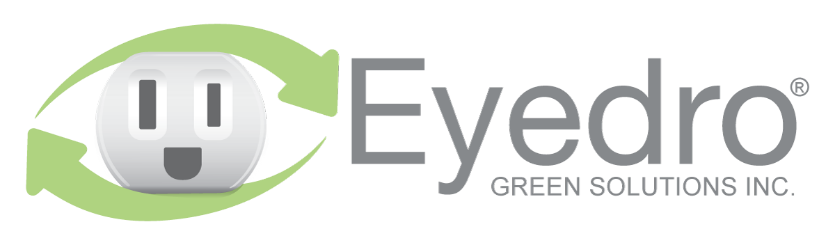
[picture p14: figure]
Media Graphics - Eyedro

Ultra-Sonic Meter Reader

TEAM MEMBERS: Darren, Austin, Carter

REPORT NUMBER: Report 5

REPORT DATE: 2022-11-03

REPORT AUTHOR: Austin Cormier

THIS WEEK’S TASKS:

T59 – Darren, Interface dev-board with Ethernet Chip

T60 – Darren, Get an IP address with Ethernet Chip attached to dev-board

T44 – Austin, Create beta PCB design for MCU module

T31 – Carter, Create block diagram for sensor module

T35 – Carter, Create schematic for sensor module circuit

PROGRESS THIS WEEK:

T57 – Darren, Modify WINC local server webpage (atmelConfig.com -> our own page) – complete.

T58 – Darren, Save SSID and PASSWORD to a network on a successful connection (WINC flash or NVM)

T42 – Austin, Create Block Diagrams for MCU module - complete.

T43 – Austin, Verify Schematic for MCU module with sponsor - *complete.

T30 – Carter, Test purchased sensors are non-defects

T36 – Carter, Verify schematic for sensor module with sponsor

NEXT WEEK’S TASKS:

T61 – Darren, On MCU powerup, determine to use Ethernet or Wi-Fi depending on if a network cable is connected to module

T62 – Darren, enable watchdog to reset module if MCU module gets stuck in an infinite loop

T45 – Verify PCB design for MCU module with sponsor

T32 – Carter, Breadboard sensor module circuit

T34 – Carter, Determine how MCU can send required frequency, do we need an oscillator or transistor to boost frequency from two sources?

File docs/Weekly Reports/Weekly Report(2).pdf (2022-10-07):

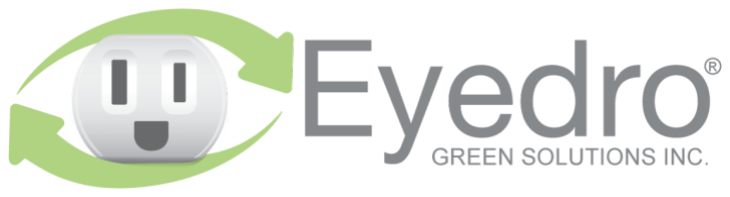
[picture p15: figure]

Ultra-Sonic Meter Reader

TEAM MEMBERS: Darren, Austin, Carter

REPORT NUMBER: Report 2

REPORT DATE: 2022-10-06

REPORT AUTHOR: Darren Morrison

THIS WEEK’S TASKS:

T4 – SAMD21 Implement/Research Timers T5 – SAMD21 Implement/Research Interrupts T6 – SAMD21 Implement/Research Watchdog T7 – SAMD21 Implement/Research Clocks

T16 – Add ATSamD20 to schematic
T17 – Add ENC28j to schematic
T18 – Add WINC1500 to schematic

T23 – Research Ultra-Sonic sensors T24 – Determine/Order piezo for testing

PROGRESS THIS WEEK:

T4 – Darren, Can work and understand basic Timers on the SAMD21 T5 – Darren, Can work and understand basic Interrupts on the SAMD21 T6 – Darren, Can work and understand basic Watchdog on the SAMD21 T7 – Darren, Can work and understand basic Clocks on the SAMD21

T16 – Austin, SAMD20 schematic is *complete.
T17 – Austin, ENC28j schematic is *complete.
T18 – Austin, WINC1500 schematic is in progress.

T23 – Carter, Main research, initial understanding complete.
T24 – Carter, Working through different options for sensors that work within our parameters.

NEXT WEEK’S TASKS:
T4 – SAMD21 Implement/Research Timers, Darren T5 – SAMD21 Implement/Research Interrupts, Darren T6 – SAMD21 Implement/Research Watchdog, Darren T7 – SAMD21 Implement/Research Clocks, Darren T9 – Interface ATWINC1500 with devboard, Darren

T18 – Add WINC to schematic, Austin
T9 – Research communicating/uploading firmware to D20, Austin T20 – Implement communication port to schematic, Austin

T24 – Determine/Order peizos, Carter
T25 – Build prototypes using ordered sensors, Carter T26 – Build testing pipe, Carter

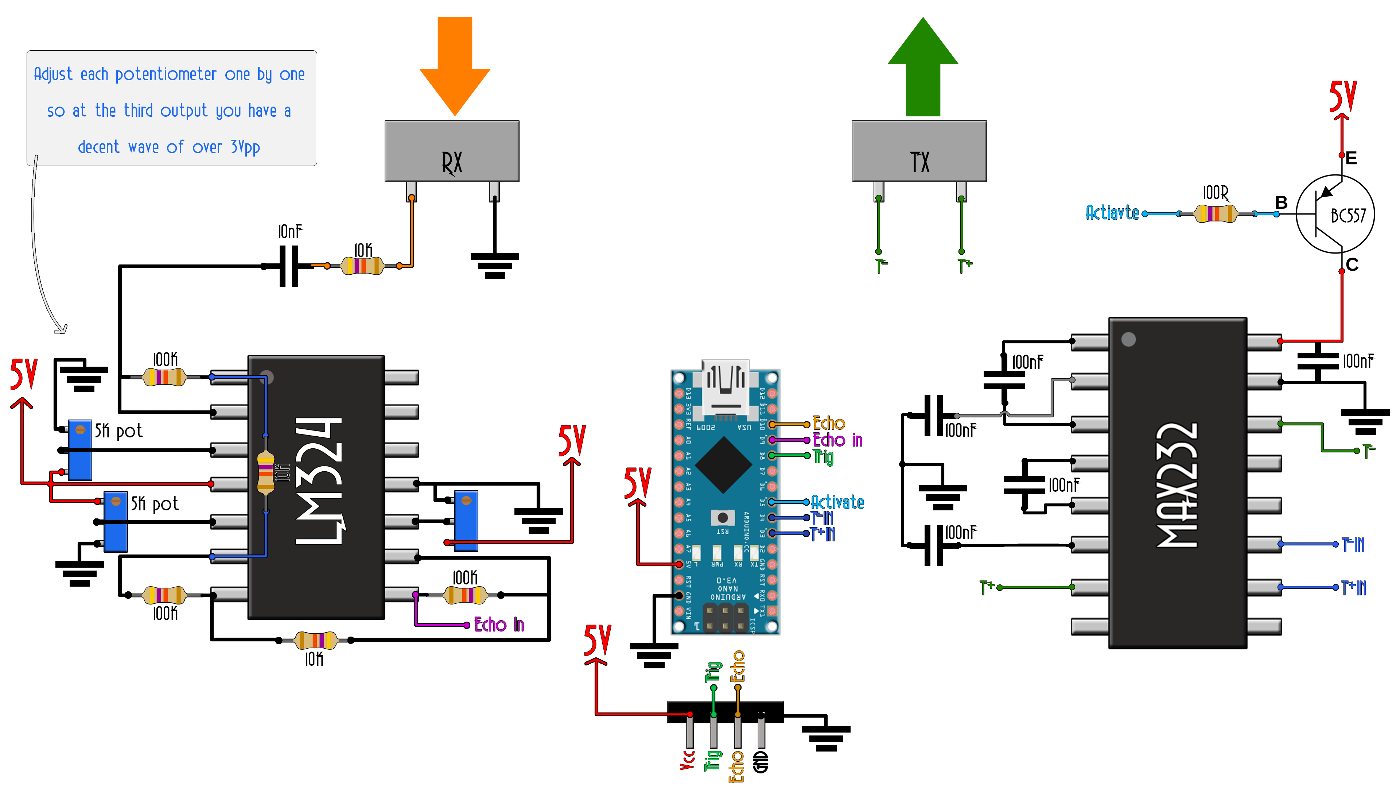
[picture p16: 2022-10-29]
Hardware/Sensor/Docs/schematic_homemade_ultrasonic_sensor.png

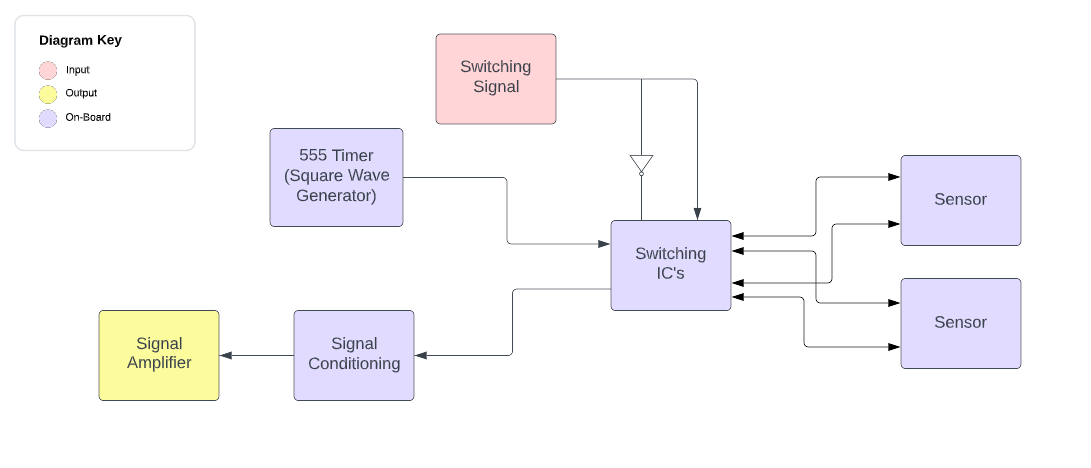
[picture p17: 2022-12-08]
docs/Flowcharts/Sensor_Block_Diagram.png

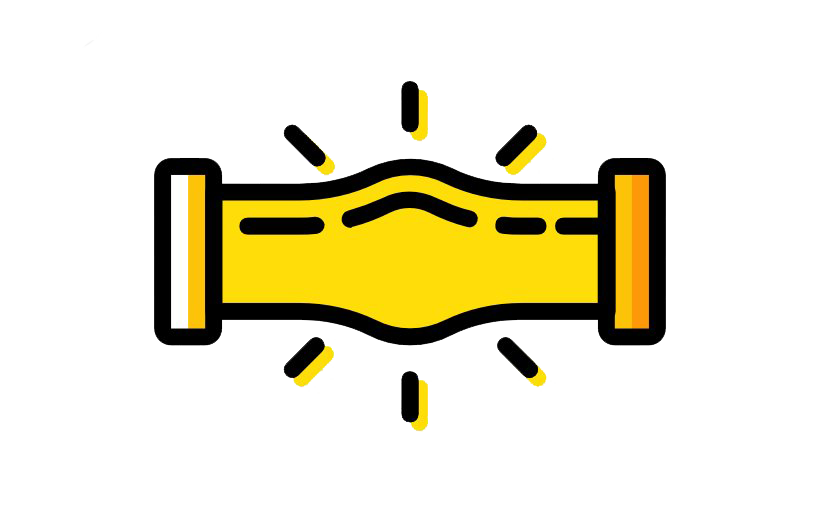
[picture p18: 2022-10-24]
Firmware/Wifi Firmware Upgrade/firmware/provisioning_webpage/Pipe.png

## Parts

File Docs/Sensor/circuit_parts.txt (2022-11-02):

#Parts List

##List
1 x MAX232ECN
1 x LM324N
1 x BC557BTF
1 x 10nF Capacitor
1 x 100Ω Resistor
3 x 10kΩ Resistor
3 x 100kΩ Resistor
3 x 5kΩ Resistor
5 x 100nF Capacitor

###Op-Amp
Texas Instruments LM324N
Link: https://www.digikey.ca/en/products/detail/texas-instruments/LM324N/277627
Datasheet: https://www.ti.com/lit/ds/symlink/lm224.pdf?HQS=dis-dk-null-digikeymode-dsf-pf-null-wwe&ts=1667311811438
Product Page: https://www.ti.com/product/LM324-N

###Voltage Driver
Texas Instruments MAX232ECN
Link: https://www.digikey.ca/en/products/detail/texas-instruments/MAX232ECN/1511013
Datasheet: https://www.ti.com/lit/ds/symlink/max232e.pdf?ts=1667364371230&ref_url=https%253A%252F%252Fwww.google.com%252F
Product Page: https://www.ti.com/product/MAX232E?keyMatch=MAX232ECN&tisearch=search-everything&usecase=OPN

###Transistor
onsemi BC557BTF
Link: https://www.digikey.ca/en/products/detail/onsemi/BC557BTF/975577
Datasheet: https://www.onsemi.com/pdf/datasheet/bc556bta-d.pdf

###Others
100, 10k, 100k Resistors
5k Potentiometers
10nF, 100nF Capacitors

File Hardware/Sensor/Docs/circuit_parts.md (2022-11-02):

# Parts List

## List
1 x MAX232ECN

1 x LM324N

1 x BC557BTF

1 x 38-40kHz Crystal

1 x 10nF Capacitor

1 x 100Ω Resistor

3 x 10kΩ Resistor

3 x 100kΩ Resistor

3 x 5kΩ Resistor

5 x 100nF Capacitor

### Op-Amp
Texas Instruments LM324N

Link: https://www.digikey.ca/en/products/detail/texas-instruments/LM324N/277627

Datasheet: https://www.ti.com/lit/ds/symlink/lm224.pdf?HQS=dis-dk-null-digikeymode-dsf-pf-null-wwe&ts=1667311811438

Product Page: https://www.ti.com/product/LM324-N

### Voltage Driver
Texas Instruments MAX232ECN

Link: https://www.digikey.ca/en/products/detail/texas-instruments/MAX232ECN/1511013

Datasheet: https://www.ti.com/lit/ds/symlink/max232e.pdf?ts=1667364371230&ref_url=https%253A%252F%252Fwww.google.com%252F

Product Page: https://www.ti.com/product/MAX232E?keyMatch=MAX232ECN&tisearch=search-everything&usecase=OPN

### Transistor
onsemi BC557BTF

Link: https://www.digikey.ca/en/products/detail/onsemi/BC557BTF/975577

Datasheet: https://www.onsemi.com/pdf/datasheet/bc556bta-d.pdf

### Crystal
Citizen Finedevice CFV-20638400AZFB

Link: https://www.digikey.ca/en/products/detail/citizen-finedevice-co-ltd/CFV-20638400AZFB/2217076

Datasheet: https://media.digikey.com/pdf/Data%20Sheets/Citizen%20PDFs/CFV-206_DS.pdf

### Others
100, 10k, 100k Resistors

5k Potentiometers

10nF, 100nF Capacitors

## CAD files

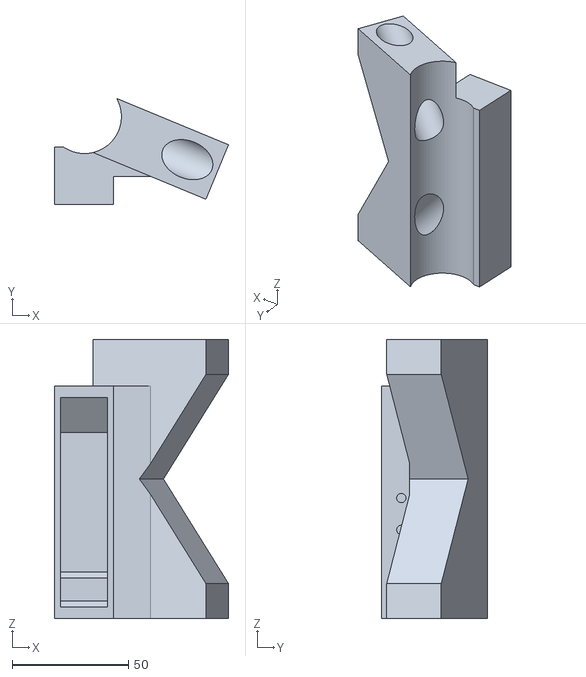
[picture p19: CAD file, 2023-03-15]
Hardware/Enclosure/Stl/DCA_Sensor_Enclosure_V0.2.1.stl
74.8 x 45.7 x 120.0

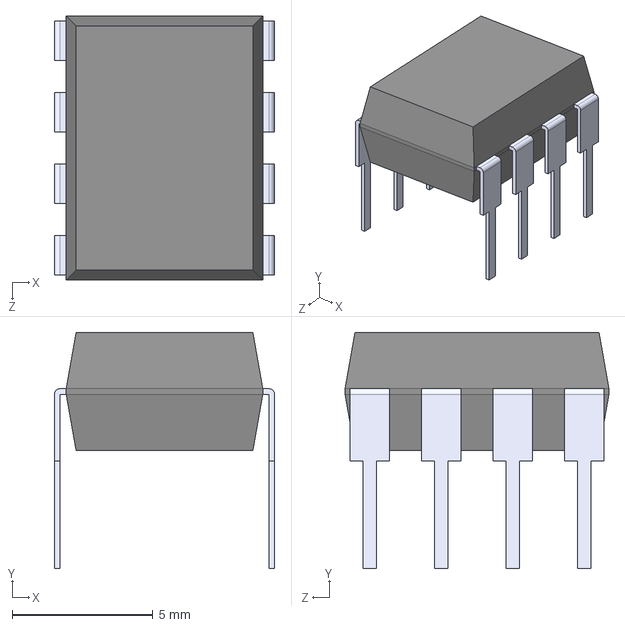
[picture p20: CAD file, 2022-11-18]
Hardware/Sensor/KiCad Symbols/MAX4528CPA_/MAX4528CPA_.step
7.82 x 8.38 x 9.38 mm

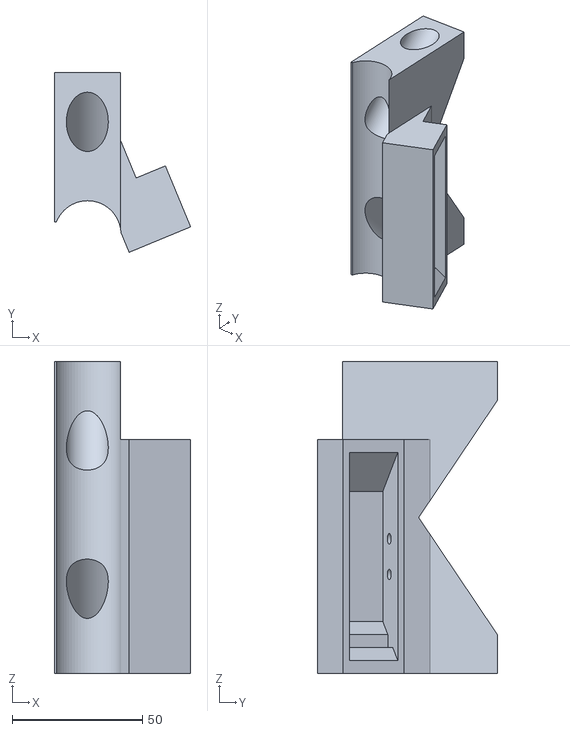
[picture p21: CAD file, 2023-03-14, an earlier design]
Hardware/Enclosure/Stl/DCA_Sensor_Enclosure_V0.1.1.stl
52.4 x 69.1 x 120.0

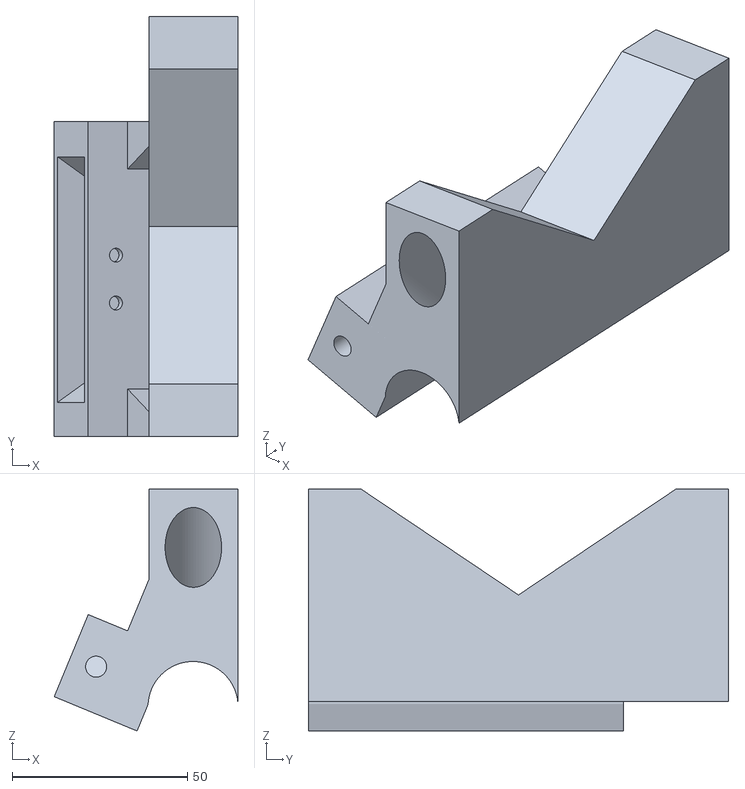
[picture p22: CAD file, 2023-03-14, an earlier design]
Hardware/Enclosure/Stl/DCA_Sensor_Enclosure_V0.0.1.stl
52.4 x 120.0 x 69.1

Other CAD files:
Hardware/Enclosure/Stl/DCA_Sensor_Enclosure_V0.0.2.stl

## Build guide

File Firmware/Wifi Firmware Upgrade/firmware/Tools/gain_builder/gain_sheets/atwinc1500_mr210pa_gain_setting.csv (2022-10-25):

ch | 1 | 2 | 3 | 4 | 5 | 6 | 7 | 8 | 9 | 10 | 11 | 12 | 13 | 14
1 | -11 | -11 | -11 | -11 | -11 | -11 | -11 | -11 | -11 | -11 | -11 | -11 | -11 | -11
2 | -11 | -11 | -11 | -11 | -11 | -11 | -11 | -11 | -11 | -11 | -11 | -11 | -11 | -11
5.5 | -10 | -10 | -10 | -10 | -10 | -10 | -10 | -10 | -10 | -10 | -10 | -10 | -10 | -10
11 | -10 | -10 | -10 | -10 | -10 | -10 | -10 | -10 | -10 | -10 | -10 | -10 | -10 | -10
6 | -10 | -6 | -6 | -6 | -6 | -6 | -6 | -6 | -6 | -6 | -6 | -6 | -6 | -8
9 | -10 | -6 | -6 | -6 | -6 | -6 | -6 | -6 | -6 | -6 | -6 | -6 | -6 | -8
12 | -10 | -6 | -6 | -6 | -6 | -6 | -6 | -6 | -6 | -6 | -6 | -6 | -6 | -8
18 | -10 | -6 | -6 | -6 | -6 | -6 | -6 | -6 | -6 | -6 | -6 | -6 | -6 | -8
24 | -10 | -6 | -6 | -6 | -6 | -6 | -6 | -6 | -6 | -6 | -6 | -6 | -6 | -8
36 | -10 | -8 | -8 | -8 | -8 | -8 | -8 | -8 | -8 | -8 | -8 | -8 | -8 | -8
48 | -10 | -10 | -10 | -10 | -10 | -10 | -10 | -10 | -10 | -10 | -10 | -10 | -10 | -10
54 | -10 | -10 | -10 | -10 | -10 | -10 | -10 | -10 | -10 | -10 | -10 | -10 | -10 | -10
MCS0 | -10 | -6 | -6 | -6 | -6 | -6 | -6 | -6 | -6 | -6 | -6 | -6 | -6 | -8
MCS1 | -10 | -6 | -6 | -6 | -6 | -6 | -6 | -6 | -6 | -6 | -6 | -6 | -6 | -8
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

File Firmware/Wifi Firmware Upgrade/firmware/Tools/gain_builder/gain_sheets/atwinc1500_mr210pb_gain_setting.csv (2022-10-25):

ch | 1 | 2 | 3 | 4 | 5 | 6 | 7 | 8 | 9 | 10 | 11 | 12 | 13 | 14
1 | -13 | -12 | -12 | -12 | -12 | -12 | -12 | -12 | -12 | -12 | -12 | -12 | -12 | -12
2 | -13 | -12 | -12 | -12 | -12 | -12 | -12 | -12 | -12 | -12 | -12 | -12 | -12 | -12
5.5 | -13 | -12 | -12 | -12 | -12 | -12 | -12 | -12 | -12 | -12 | -12 | -12 | -11.5 | -12
11 | -13 | -12 | -12 | -12 | -12 | -12 | -12 | -12 | -12 | -12 | -12 | -12 | -11.5 | -12
6 | -14 | -8 | -8 | -8 | -8 | -8 | -8 | -8 | -8 | -8 | -10 | -8 | -11 | -30
9 | -14 | -8 | -8 | -8 | -8 | -8 | -8 | -8 | -8 | -8 | -10 | -8 | -11 | -30
12 | -14 | -8 | -8 | -8 | -8 | -8 | -8 | -8 | -8 | -8 | -10 | -8 | -11 | -30
18 | -14 | -8 | -8 | -8 | -8 | -8 | -8 | -8 | -8 | -8 | -10 | -8 | -11 | -30
24 | -14 | -8 | -8 | -8 | -8 | -8 | -8 | -8 | -8 | -8 | -10 | -8 | -11 | -30
36 | -14 | -8 | -8 | -8 | -8 | -8 | -8 | -8 | -8 | -8 | -10 | -8 | -11 | -30
48 | -14 | -8 | -8 | -8 | -8 | -8 | -8 | -8 | -8 | -8 | -10 | -8 | -11 | -30
54 | -14 | -9 | -9 | -9 | -9 | -9 | -9 | -9 | -9 | -9 | -10 | -9 | -11 | -30
MCS0 | -15 | -8 | -8 | -8 | -8 | -8 | -8 | -8 | -8 | -8 | -11 | -8 | -11 | -30
MCS1 | -15 | -8 | -8 | -8 | -8 | -8 | -8 | -8 | -8 | -8 | -11 | -8 | -11 | -30
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

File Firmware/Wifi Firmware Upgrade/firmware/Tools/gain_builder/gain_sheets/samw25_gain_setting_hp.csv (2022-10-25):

ch | 1 | 2 | 3 | 4 | 5 | 6 | 7 | 8 | 9 | 10 | 11 | 12 | 13 | 14
1 | -11.5 | -10 | -10 | -10 | -10 | -10 | -10 | -10 | -10 | -10 | -10 | -10 | -10.5 | -10.5
2 | -11.5 | -10 | -10 | -10 | -10 | -10 | -10 | -10 | -10 | -10 | -10 | -10 | -10.5 | -10.5
5.5 | -11.5 | -10 | -10 | -10 | -10 | -10 | -10 | -10 | -10 | -10 | -10 | -10 | -10.5 | -10.5
11 | -11.5 | -10 | -10 | -10 | -10 | -10 | -10 | -10 | -10 | -10 | -10 | -10 | -10.5 | -10.5
6 | -10 | -9.5 | -9.5 | -9.5 | -9.5 | -9.5 | -9.5 | -9.5 | -9.5 | -9.5 | -9.5 | -9.5 | -10 | -10
9 | -10 | -9.5 | -9.5 | -9.5 | -9.5 | -9.5 | -9.5 | -9.5 | -9.5 | -9.5 | -9.5 | -9.5 | -10 | -10
12 | -10 | -9.5 | -9.5 | -9.5 | -9.5 | -9.5 | -9.5 | -9.5 | -9.5 | -9.5 | -9.5 | -9.5 | -10 | -10
18 | -10 | -9.5 | -9.5 | -9.5 | -9.5 | -9.5 | -9.5 | -9.5 | -9.5 | -9.5 | -9.5 | -9.5 | -10 | -10
24 | -10 | -9.5 | -9.5 | -9.5 | -9.5 | -9.5 | -9.5 | -9.5 | -9.5 | -9.5 | -9.5 | -9.5 | -10 | -10
36 | -10 | -9.5 | -9.5 | -9.5 | -9.5 | -9.5 | -9.5 | -9.5 | -9.5 | -9.5 | -9.5 | -9.5 | -10 | -10
48 | -10 | -9.5 | -9.5 | -9.5 | -9.5 | -9.5 | -9.5 | -9.5 | -9.5 | -9.5 | -9.5 | -9.5 | -10 | -10
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

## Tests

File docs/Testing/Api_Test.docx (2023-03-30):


DCA Testing

API

2023-03-22

Table of Contents

1.0 Purpose……………………………………………………………………………………………………………………………… 2
2.0 Overview……………………………………………………………………………………………………………………………. 2
3.0 Scope…………………………………………………………………………………………………………………………………. x
  3.1 Login……………………………………………………………………………………………………………… x
  3.2 Signup/User.Add……………………………………………………………………………………..……. x
  3.3 ResetPassword ………………………………………………………………………………………….…. x
  3.4 User.Del ………………………………………………………………………………………………….……. x
  3.5 Data.Get ………………………………………………………………………………………………………. x
4.0 Results………………………………………………………………………………………………………………………………. x
5.0 Analysis……………………………………………………………………………………………………………………………… x
1.0 Purpose

The API is the main connection between the frontend, and backend. This allows the client(user) to use a responsive, interactive site that presents realtime data. If this connection is not working or returning unexpected results or errors, the user’s experience will decrease in value and or be no more than a static html page. Currently the API has endpoints for user and data.

2.0 Overview

The API turns a static page on the internet, into an interactive webpage that allows a user to do as little work as possible. Even from the first point of contact; the login page. The user is presented with the task of logging in, signing up or resetting their password. If any of these tools(endpoints) are broken or unregistered, the user’s experience will be degraded.

Once logged in, any configurations the user selects will affect the async data get functionality. If this endpoint fails, the graphs/data analysis will not be updating, and a user may not be getting the flow/volume insights they expect.

- Screenshots/pictures
3.0 Scope

The entirety of the API endpoints will be tested. Each endpoint for data, and user functionality will be tested through the browser/POST. All of these endpoints will be tested rigorously.

3.1 Login

https://{Domain}/api.php?Cmd=Login&Email=&Password=

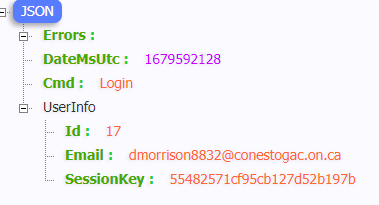
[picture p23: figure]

Expected results is an empty error array, the current time, the command requested, and a UserInfo array containing the UserId, Email and new SessionKey.

Unexpected results would be errors in the error array.

3.2 Signup/User.Add

https://{Domain}/api.php?Cmd=Signup&Email=&Password=

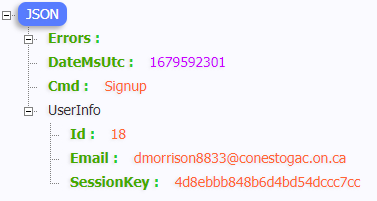
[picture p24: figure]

Expected results is an empty error array, the current time, the command requested, and a UserInfo array containing the UserId, Email and new SessionKey.

Unexpected results would be errors in the error array.

3.3 ResetPassword

https://{Domain}/api.php?Cmd=ResetPassword&Email=&Password=&PasswordOld=

Expected results is an empty error array, the current time, the command requested

Unexpected results would be errors in the error array.

3.4 User.Del

https://{Domain}/api.php?Cmd=User.Del&Email=&Password=

Expected results is an empty error array, the current time, the command requested

Unexpected results would be errors in the error array.

3.5 Data.Get

https://{Domain}/api.php?Cmd=getdata

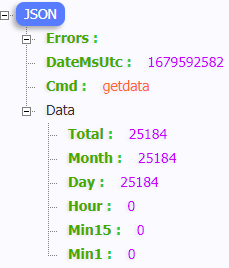
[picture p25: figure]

Expected results is an empty error array, the current time, the command requested, and a data array containing Total, Month, Hour, Min15, and Min1.

Unexpected results would be errors in the error array.

4.0 Results

Number of Test Cases Planned | Number of Test Cases Executed | Number of Tests Cases Passed | Number of Test Cases Failed
18 | 0 | 0 | 0

Tests were carried out for each scope one at a time, three times each, for a total of 18 test cases.

5.0 Analysis

All test cases were passed without issue. Every endpoint returned an expected value and was repeatable. This ensures the user’s experience is as expected everytime.

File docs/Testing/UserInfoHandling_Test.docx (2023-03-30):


DCA Testing

User Information Handling

2023-03-22

Table of Contents

1.0 Purpose ……………………………………………………………………………………………………………………………… 2
2.0 Overview …………………………………………………………………………………………………………………………… 2
3.0 Scope …………………………………………………………………………………………………………………………………. 2
  3.1 User Log In ……………………………………………………………………………………………………………… 2
  3.2 User Creation ……………………………………………………………………………………………………… 2/3
  3.3 User Deletion …………………………………………………………………………………………………………. 3
  3.4 Reset Password ……………………………………………………………………………………………………… 3
4.0 Results ………………………………………………………………………………………………………………………………. 3
5.0 Analysis ……………………………………………………………………………………………………………………………… 3
6.0 Appendix …………………………………………………………………………………………………………………………… 4
1.0 Purpose

The user form greets the user upon arrival at our website, its purpose it to be visually appealing, while also being fully functional. The design of the launch page is meant to be self-explanatory. These series of tests will be important because, to the end user, this is the first step in their journey with our product. We must ensure that all aspects are working properly.

2.0 Overview

The launch page is a starting point for our users. It displays a place for them to log in to their pre-existing account (and have the browser remember their credentials upon request), create an account, and reset a forgotten password.

The feature works by taking in user provided information in a form, sending the information to a database, validating the user’s credentials, and either granting or denying them access. The user will be granted access if, upon log in attempt, they have an account with us, and their username/email and password are correct. In all other cases, the user should be denied access.

Creating a user works by taking user information from a form and storing it in our database. This information can then be used to grant them access at log in.

Resetting a password works by taking the users email and validating that they do have an existing account with us. They will then be sent an email with a new password to use, which they can change at any time within their profile configuration settings.

3.0 Scope

The entirety of the initial launch page will be tested. This page contains many parts including user log in, user creation, user deletion, the ‘remember me’ button, and resetting a users’ password. All of these features will be tested rigorously.

3.1 User Log In

A successful test for user log in would follow these steps:

1. The user arrives at the launch page (Fig. 1)
2. The user inputs their username and password (Fig. 2)
3. If correct, the user will be granted access to their statistics (Fig. 3)
4. If not, they will receive an error message, and be denied access (Fig. 4)

3.2 User Creation

A successful test for user creation would follow these steps:

1. The user arrives at the launch page (Fig. 1)
2. The user clicks “create a new user” button
3. The user inputs their email and password (Fig. 5)
4. The user’s input is sent to the database accurately

3.3 User Deletion

A successful test for user deletion would follow these steps:

1. The user arrives at the launch page (Fig. 1)
2. The user uses their credentials to log in to their account
3. The user navigates to the “configuration” tab (Fig. 6)
4. The user enters their password and selects the “delete user” button (Fig. 7)
5. The user’s information is removed from the database

3.4 Reset Password

A successful test for resetting user password would follow these steps:

1. The user arrives at the launch page (Fig. 1)
2. The user clicks the “forgot password” button
3. The user enters their credentials along with a new password (Fig. 8)
4. The user is able to log in to their account with the new password

The intuitiveness of the website and launch page is not being tested because we do not have the materials required to perform accurate human tests. It will be assumed that the user is able to navigate to the proper checkboxes, buttons, and menus without issue.

The testing environment will be a manual setup where the user will be demonstrating the capability of the test while also thinking intuitively about the steps they’re taking. This test will require a user, a computer, a browser, and an internet connection.

4.0 Results

Number of Test Cases Planned | Number of Test Cases Executed | Number of Tests Cases Passed | Number of Test Cases Failed
20 | 20 | 20 | 0

Tests were carried out for each scope one at a time, five times each, for a total of 20 test cases.

5.0 Analysis

All test cases were passed without issue. The user provided little feedback as to potential improvements, but said we could make the website more accessible, with larger font sizes and colours that contrast further. We will take this into consideration.

6.0 Appendix

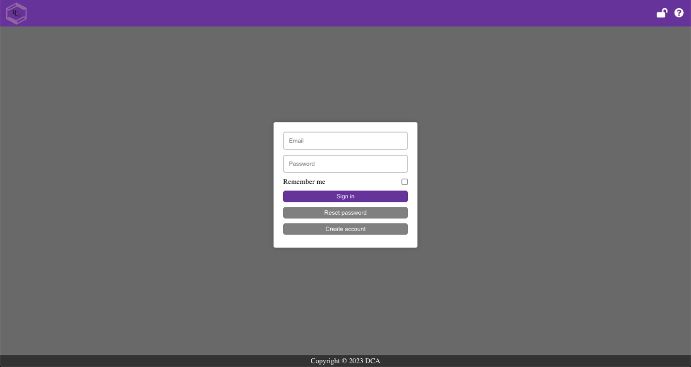
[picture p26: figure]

Figure 1. Launch page

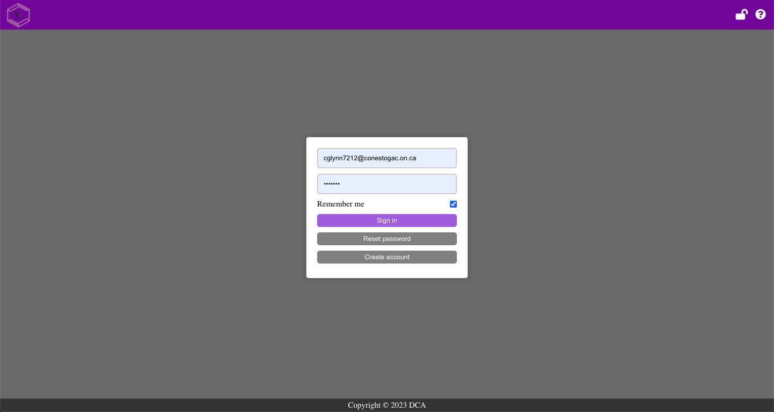
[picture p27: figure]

Figure 2. Enter user credentials and click “Remember me” button

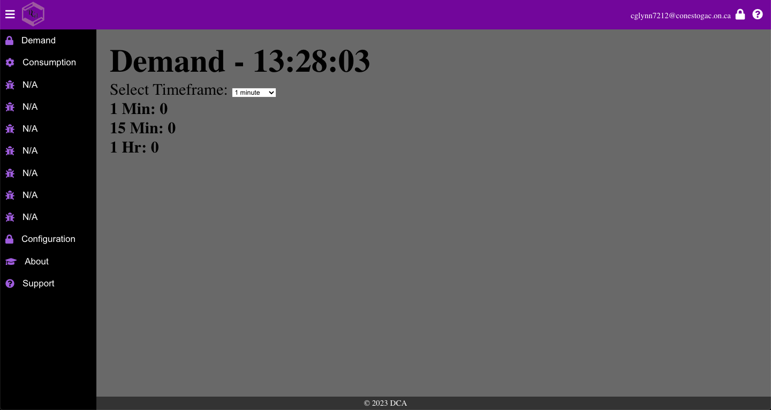
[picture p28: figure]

Figure 3. User is granted access to their statistics

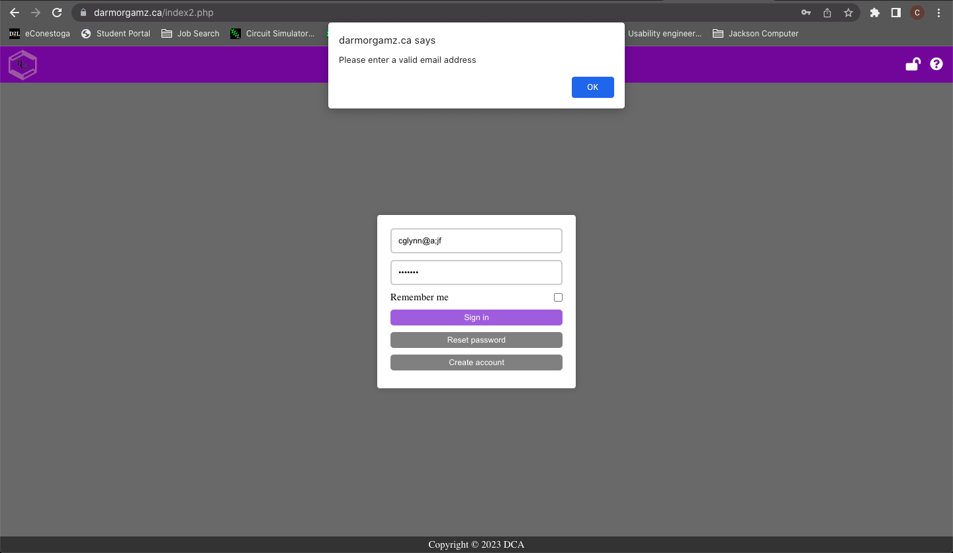
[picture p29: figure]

Figure 4. Incorrect credentials with error message

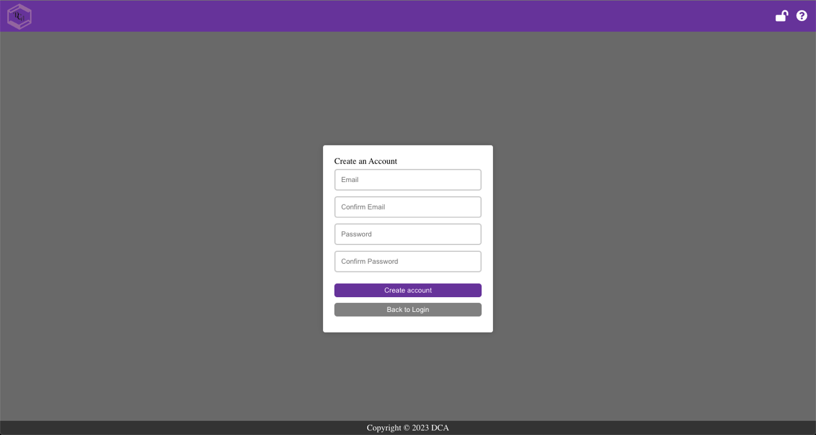
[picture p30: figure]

Figure 5. Menu for creating a new account

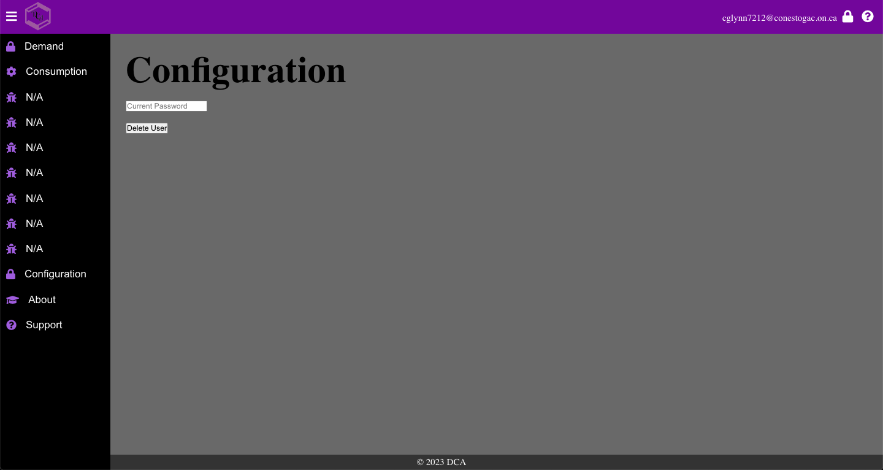
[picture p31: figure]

Figure 6. “Configuration” tab in the website menu

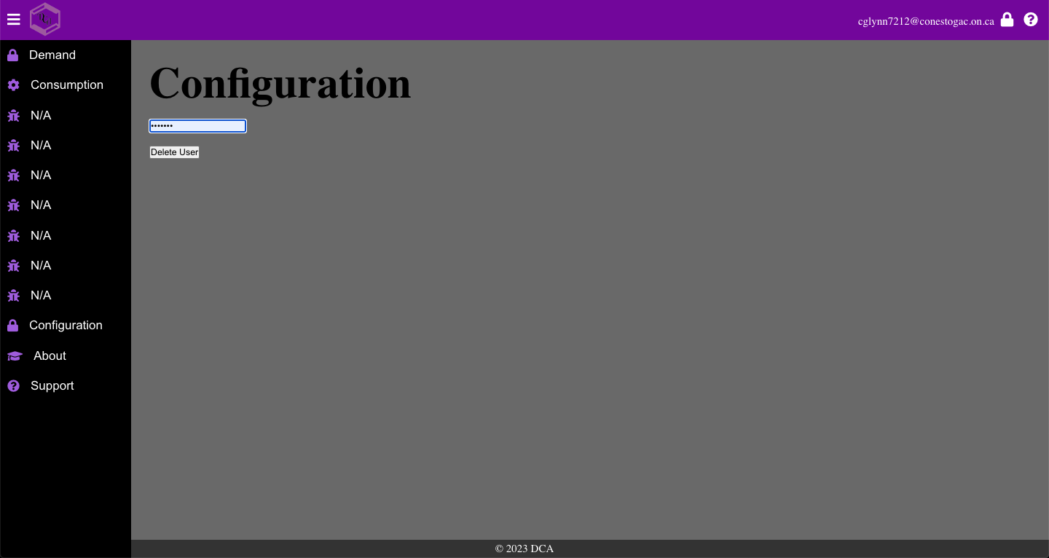
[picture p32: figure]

Figure 7. Deleting user menu with password inputted


Figure 8. Reset password menu

4 DCA, Inc.

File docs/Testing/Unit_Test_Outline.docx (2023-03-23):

Purpose

- What is this feature used for? (general; high level)
- Why is this test important?

Overview

- What does this feature do?
- How does the feature work?
- What does a successful test look like?
- Screenshots/pictures

Scope

- What is being tested? (generally and break it down into modules)
- What is not being tested? Why?
- Test environment
- Test tools

Procedure

- How did you test?
- Step by step instructions

Results

- Number of test cases planned
- Number of test cases executed
- Number of test cases passed
- Number of test cases failed
- Graphs/Charts

Analysis

- What happened? Why?
- Did anything go wrong? Why?
- How will anything be fixed?

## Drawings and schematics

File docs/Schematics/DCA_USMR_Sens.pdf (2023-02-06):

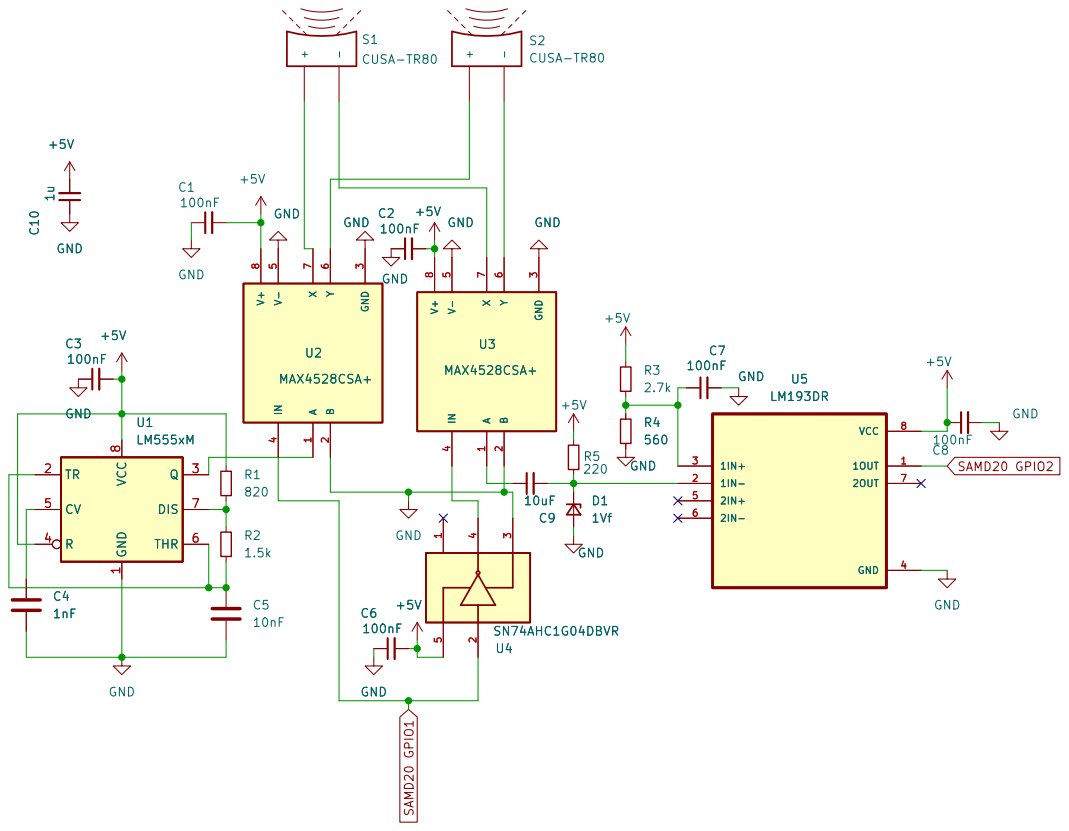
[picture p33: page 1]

Id: 1/1 Title: Sensor Module

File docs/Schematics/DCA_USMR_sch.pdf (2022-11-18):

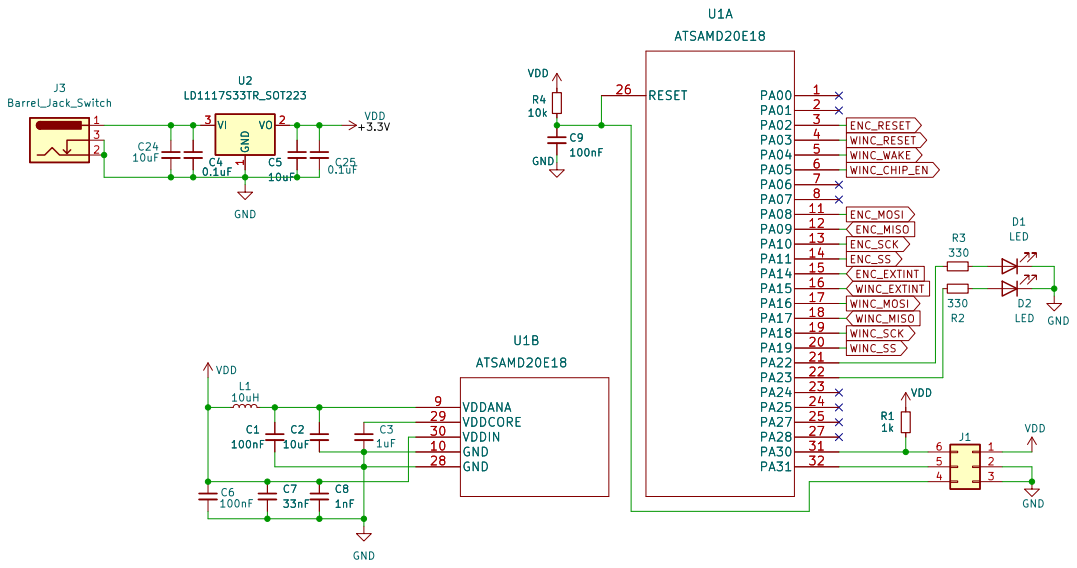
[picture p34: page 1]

Id: 1/3 Title: ATSAMD20E18 Control Circuit

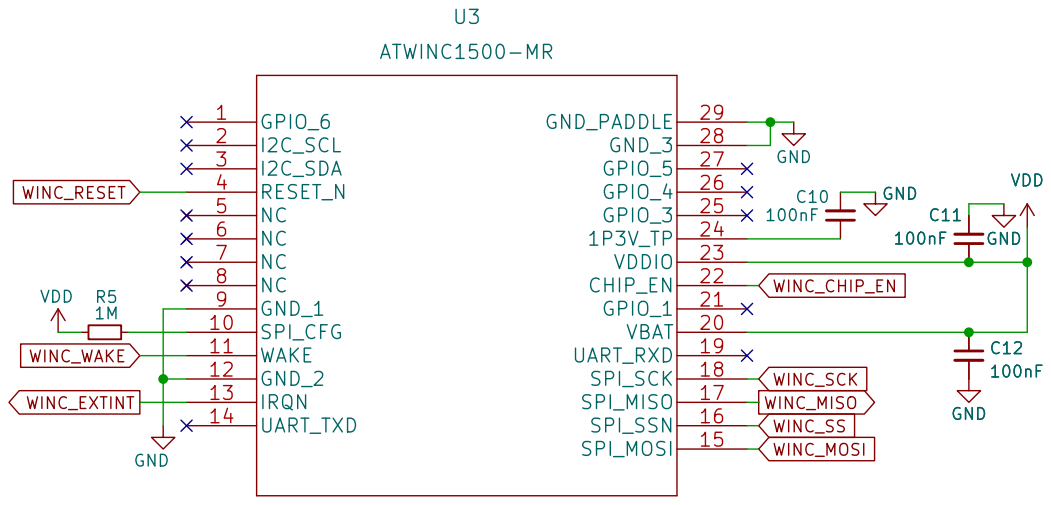
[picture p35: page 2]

File: WINC_C.kicad_sch
Id: 2/3 Title: ATWINC1500-MR Control Circuit With Antenna

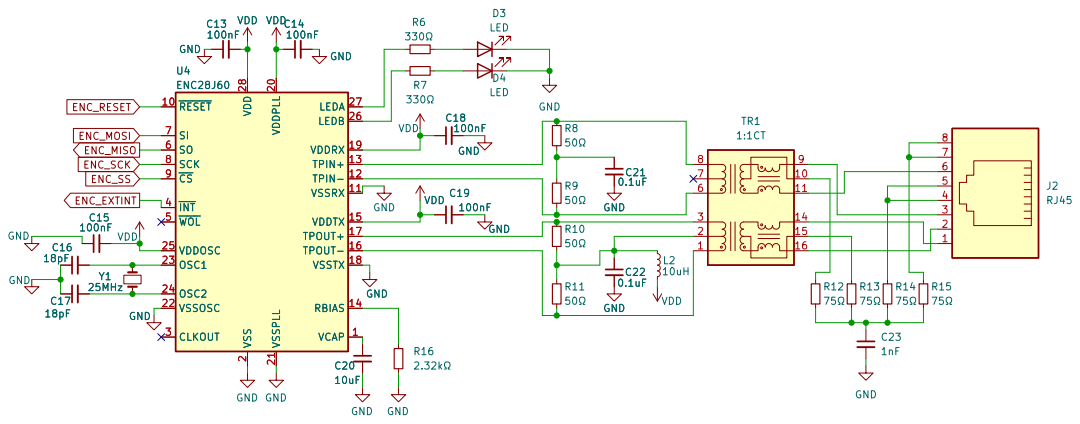
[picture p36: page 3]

2 VDDPLL 20 VSSPLL 21 VSSOSC 22 OSC1 23 OSC2 24 VDDOSC 25

File: Ethernet_C.kicad_sch
Id: 3/3 Title: ENC28J60 Control Circuit

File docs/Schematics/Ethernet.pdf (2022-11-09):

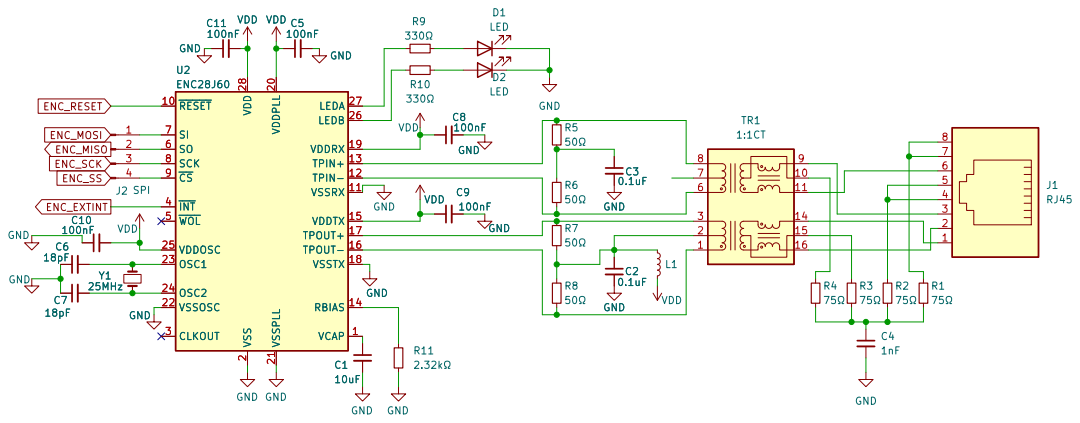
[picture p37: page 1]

2 VDDPLL 20 VSSPLL 21 VSSOSC 22 OSC1 23 OSC2 24 VDDOSC 25

File: Ethernet.kicad_sch Sheet: / DCA

Id: 1/1 Title: ENC28J60 Control Circuit

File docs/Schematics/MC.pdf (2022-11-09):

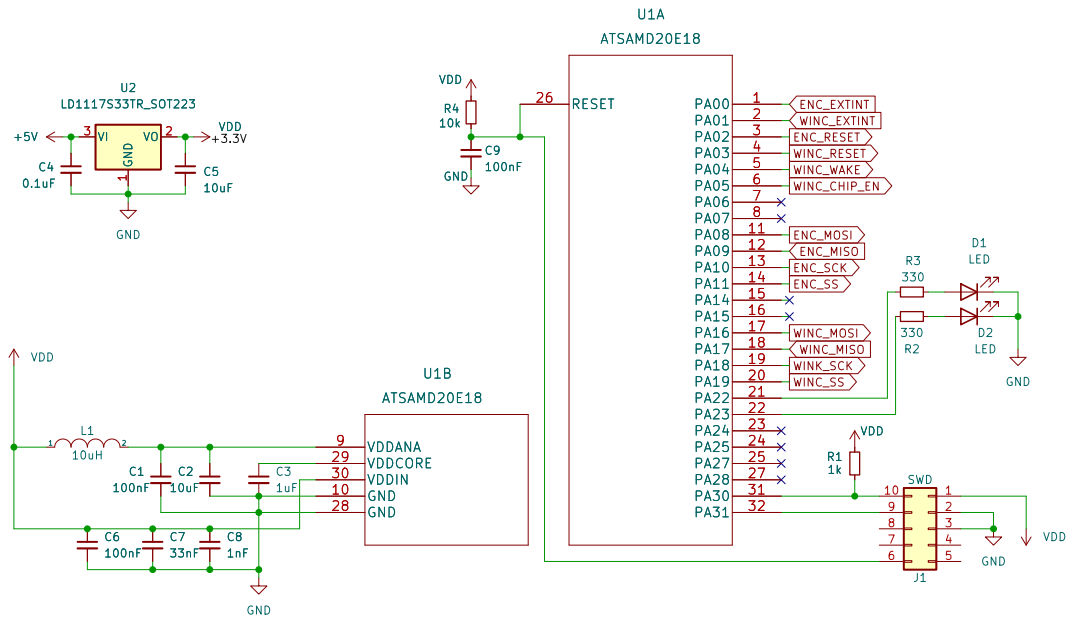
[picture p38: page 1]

Id: 1/1 Title: ATSAMD20E18 Control Circuit

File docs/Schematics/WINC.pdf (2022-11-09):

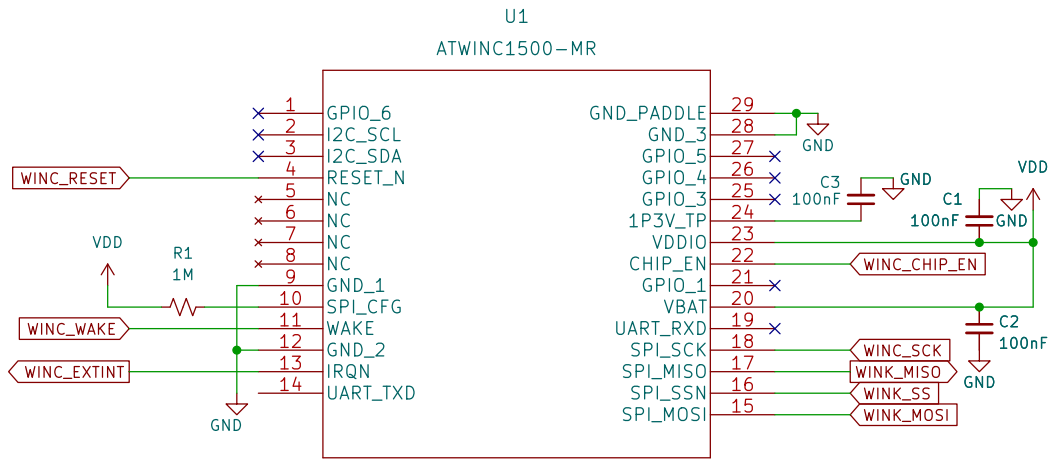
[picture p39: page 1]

File: WINC.kicad_sch Sheet: / DCA

Id: 1/1 Title: ATWINC1500-MR Control Circuit With Antenna

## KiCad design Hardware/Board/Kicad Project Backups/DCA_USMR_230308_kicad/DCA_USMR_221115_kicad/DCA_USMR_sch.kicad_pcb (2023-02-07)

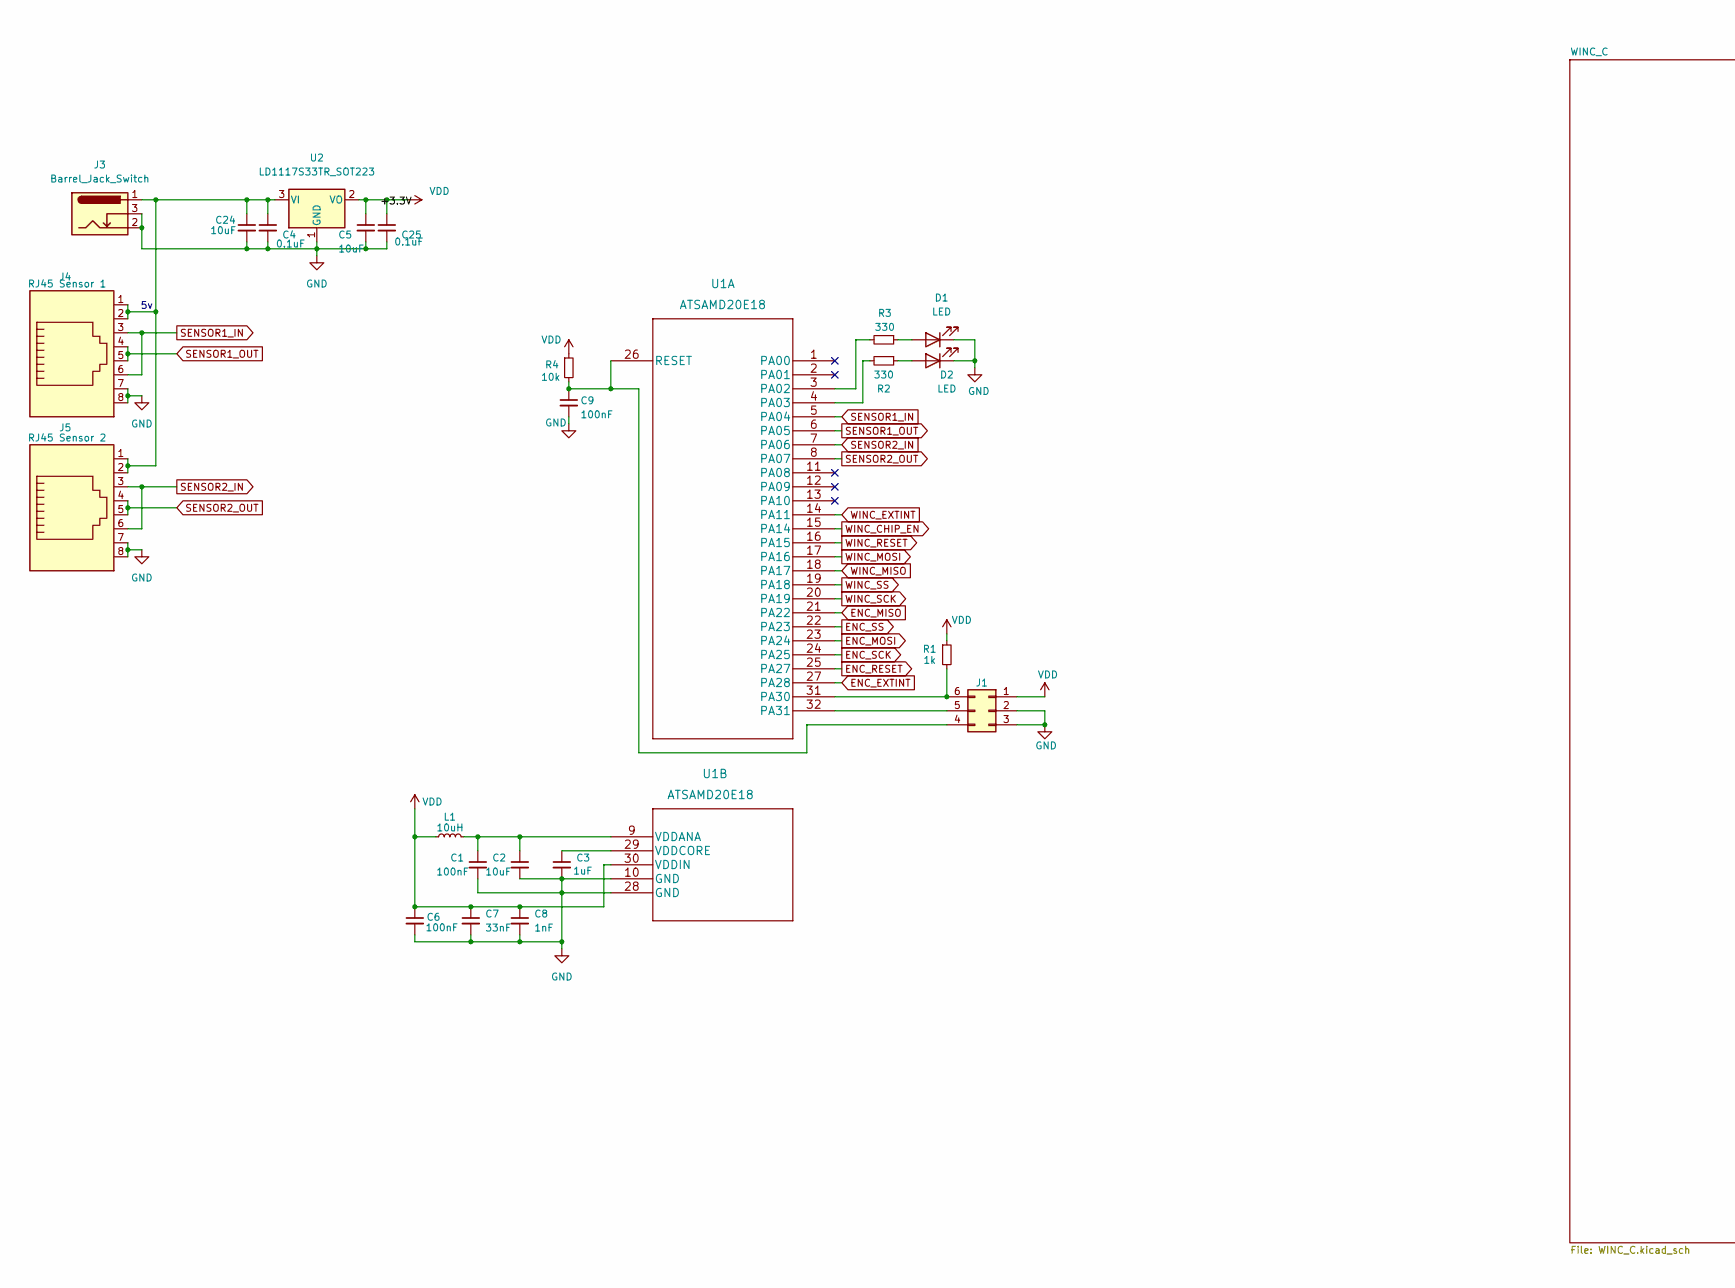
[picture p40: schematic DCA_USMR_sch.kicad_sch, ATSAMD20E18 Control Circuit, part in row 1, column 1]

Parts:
C1, C6, C9: 100nF; C_0402_1005Metric
C2, C5, C24: 10uF; C_1206_3216Metric
C3: 1uF; C_0402_1005Metric
C4, C25: 0.1uF; C_0402_1005Metric
C7: 33nF; C_0402_1005Metric
C8: 1nF; C_0402_1005Metric
D1, D2: LED; LED_0402_1005Metric
J1: Conn_02x03_Counter_Clockwise; PinHeader_2x03_P2.00mm_Vertical
J3: Barrel_Jack_Switch; CUI_PJ-018H-SMT-TR
J4: RJ45 Sensor 1; RJ45_Plug_Metz_AJP92A8813
J5: RJ45 Sensor 2; RJ45_Plug_Metz_AJP92A8813
L1: 10uH; L_0603_1608Metric
R1: 1k; R_0402_1005Metric
R2, R3: 330; R_0402_1005Metric
R4: 10k; R_0402_1005Metric
U1: ATSAMD20E18; ATSAMD20E18A-AU
U2: LD1117S33TR_SOT223; SOT-223-3_TabPin2

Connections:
ENC_EXTINT: U1.27 (PA28); also elsewhere on the board
ENC_MISO: U1.21 (PA22); also elsewhere on the board
ENC_MOSI: U1.23 (PA24); also elsewhere on the board
ENC_RESET: U1.25 (PA27); also elsewhere on the board
ENC_SCK: U1.24 (PA25); also elsewhere on the board
ENC_SS: U1.22 (PA23); also elsewhere on the board
GND: C1.2, C2.2, C3.2, C4.2, C5.2, C6.2, C7.2, C8.2, C9.2, C24.2, C25.2, D1.1 (K), D2.1 (K), J1.2, J1.3, J3.2, J3.3, J4.7, J4.8, J5.7, J5.8, U1.10 (GND), U1.28 (GND), U2.1 (GND); also elsewhere on the board
unnamed: C1.1, C2.1, L1.2, U1.9 (VDDANA)
unnamed: C3.1, U1.29 (VDDCORE)
unnamed: C9.1, J1.4, R4.2, U1.26 (RESET)
unnamed: C4.1, C24.1, J3.1, J3.1A, J4.1, J4.2, J5.1, J5.2, U2.3 (VI)
unnamed: D1.2 (A), R3.1
unnamed: D2.2 (A), R2.1
unnamed: J1.5, U1.32 (PA31)
unnamed: J1.6, R1.2, U1.31 (PA30)
unnamed: R3.2, U1.3 (PA02)
unnamed: R2.2, U1.4 (PA03)
SENSOR1_IN: J4.3, J4.6, U1.5 (PA04)
SENSOR1_OUT: J4.4, J4.5, U1.6 (PA05)
SENSOR2_IN: J5.3, J5.6, U1.7 (PA06)
SENSOR2_OUT: J5.4, J5.5, U1.8 (PA07)
VDD: C5.1, C6.1, C7.1, C8.1, C25.1, J1.1, L1.1, R1.1, R4.1, U1.30 (VDDIN), U2.2 (VO); also elsewhere on the board
WINC_CHIP_EN: U1.15 (PA14); also elsewhere on the board
WINC_EXTINT: U1.14 (PA11); also elsewhere on the board
WINC_MISO: U1.18 (PA17); also elsewhere on the board
WINC_MOSI: U1.17 (PA16); also elsewhere on the board
WINC_RESET: U1.16 (PA15); also elsewhere on the board
WINC_SCK: U1.20 (PA19); also elsewhere on the board
WINC_SS: U1.19 (PA18); also elsewhere on the board

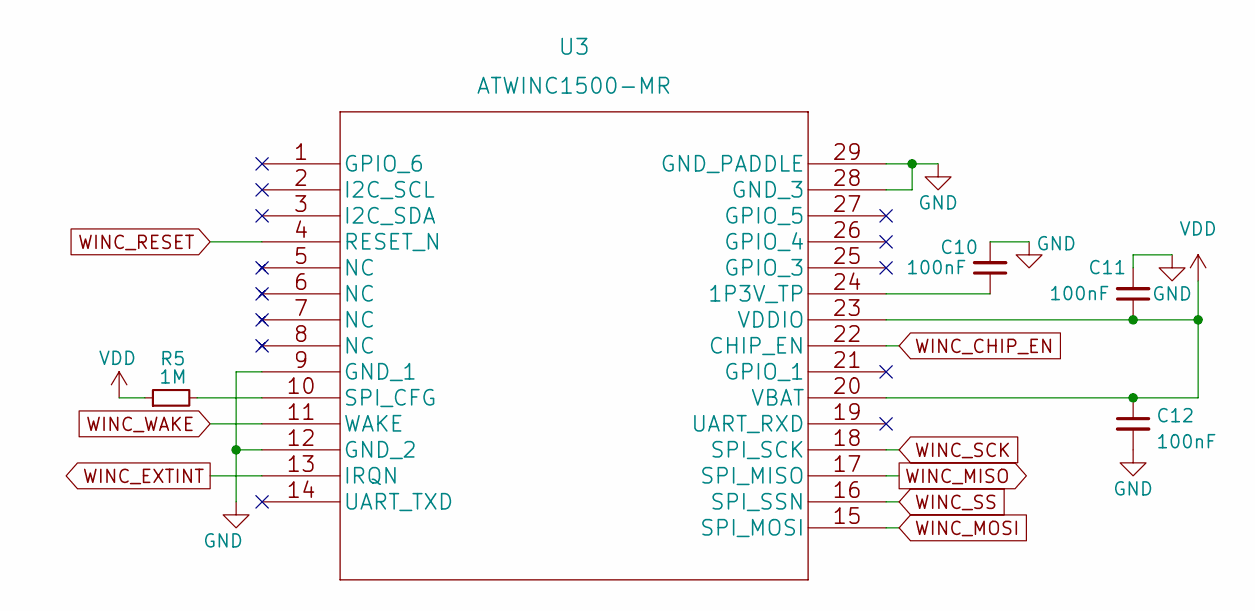
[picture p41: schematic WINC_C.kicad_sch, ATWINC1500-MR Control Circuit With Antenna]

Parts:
C10, C11, C12: 100nF; C_0402_1005Metric
R5: 1M; R_0402_1005Metric
U3: ATWINC1500-MR; ATWINC1500-MR210PB1961

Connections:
GND: C10.2, C11.2, C12.2, U3.9 (GND_1), U3.12 (GND_2), U3.28 (GND_3), U3.29 (GND_PADDLE); also elsewhere on the board
unnamed: C10.1, U3.24 (1P3V_TP)
unnamed: R5.2, U3.10 (SPI_CFG)
VDD: C11.1, C12.1, R5.1, U3.20 (VBAT), U3.23 (VDDIO); also elsewhere on the board
WINC_CHIP_EN: U3.22 (CHIP_EN); also elsewhere on the board
WINC_EXTINT: U3.13 (IRQN); also elsewhere on the board
WINC_MISO: U3.17 (SPI_MISO); also elsewhere on the board
WINC_MOSI: U3.15 (SPI_MOSI); also elsewhere on the board
WINC_RESET: U3.4 (RESET_N); also elsewhere on the board
WINC_SCK: U3.18 (SPI_SCK); also elsewhere on the board
WINC_SS: U3.16 (SPI_SSN); also elsewhere on the board
WINC_WAKE: U3.11 (WAKE)

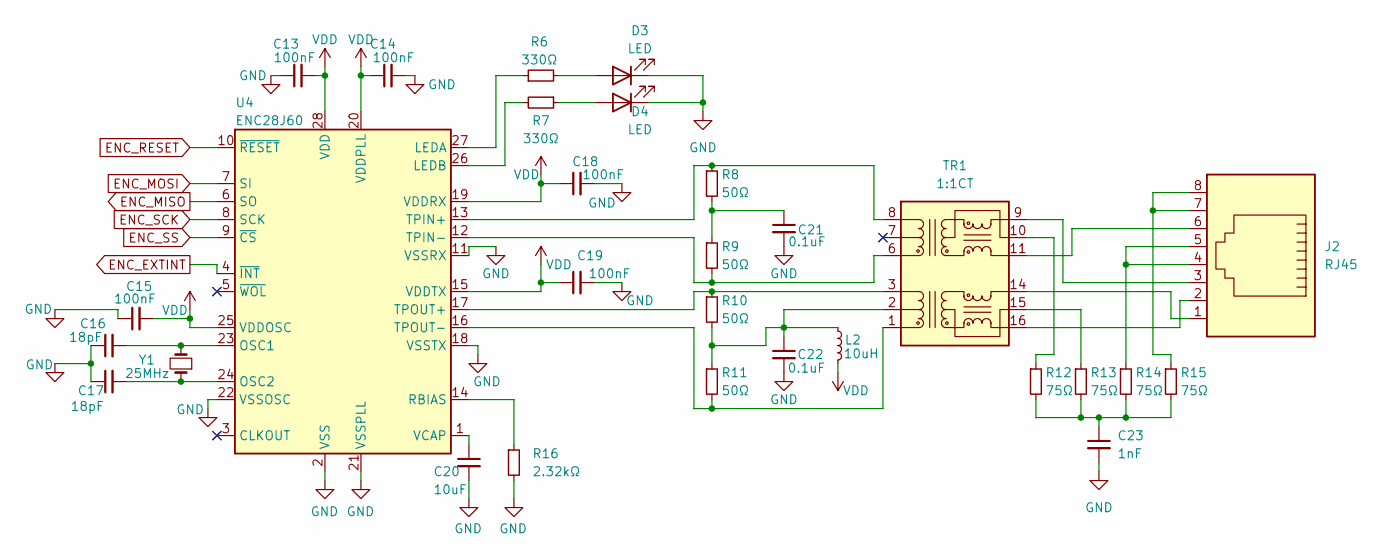
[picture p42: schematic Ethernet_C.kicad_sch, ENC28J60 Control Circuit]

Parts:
C13, C14, C15, C18, C19: 100nF; C_0402_1005Metric
C16, C17: 18pF; C_0402_1005Metric
C20: 10uF; C_1206_3216Metric
C21, C22: 0.1uF; C_0402_1005Metric
C23: 1nF; C_0402_1005Metric
D3, D4: LED; LED_0402_1005Metric
J2: RJ45; RJ45_Plug_Metz_AJP92A8813
L2: 10uH; L_0603_1608Metric
R6, R7: 330Ω; R_0402_1005Metric
R8, R9, R10, R11: 50Ω; R_0402_1005Metric
R12, R13, R14, R15: 75Ω; R_0402_1005Metric
R16: 2.32kΩ; R_0402_1005Metric
TR1: 1:1CT; Transformer_Ethernet_Bourns_PT61017PEL
U4: ENC28J60; SSOP-28_5.3x10.2mm_P0.65mm
Y1: 25MHz; XTAL_ECS-160-20-4X

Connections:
ENC_EXTINT: U4.4 (~INT); also elsewhere on the board
ENC_MISO: U4.6 (SO); also elsewhere on the board
ENC_MOSI: U4.7 (SI); also elsewhere on the board
ENC_RESET: U4.10 (~RESET); also elsewhere on the board
ENC_SCK: U4.8 (SCK); also elsewhere on the board
ENC_SS: U4.9 (~CS); also elsewhere on the board
GND: C13.1, C14.2, C15.1, C16.1, C17.1, C18.2, C19.2, C20.2, C21.2, C22.2, C23.2, D3.1 (K), D4.1 (K), R16.2, U4.2 (VSS), U4.11 (VSSRX), U4.18 (VSSTX), U4.21 (VSSPLL), U4.22 (VSSOSC); also elsewhere on the board
unnamed: C16.2, U4.23 (OSC1), Y1.2
unnamed: C17.2, U4.24 (OSC2), Y1.1
unnamed: C20.1, U4.1 (VCAP)
unnamed: C21.1, R8.2, R9.1
unnamed: C22.1, L2.1, R10.2, R11.1, TR1.2 (C_TD)
unnamed: C23.1, R12.2, R13.2, R14.2, R15.2
unnamed: D3.2 (A), R6.2
unnamed: D4.2 (A), R7.1
unnamed: J2.1, TR1.14 (TX-)
unnamed: J2.2, TR1.16 (TX+)
unnamed: J2.3, TR1.9 (RX-)
unnamed: J2.4, J2.5, R14.1
unnamed: J2.6, TR1.11 (RX+)
unnamed: J2.7, J2.8, R15.1
unnamed: R6.1, U4.27 (LEDA)
unnamed: R7.2, U4.26 (LEDB)
unnamed: R8.1, TR1.8 (RD-), U4.13 (TPIN+)
unnamed: R9.2, TR1.6 (RD+), U4.12 (TPIN-)
unnamed: R10.1, TR1.3 (TD-), U4.17 (TPOUT+)
unnamed: R11.2, TR1.1 (TD+), U4.16 (TPOUT-)
unnamed: R12.1, TR1.10 (C_RX)
unnamed: R13.1, TR1.15 (C_TX)
unnamed: R16.1, U4.14 (RBIAS)
VDD: C13.2, C14.1, C15.2, C18.1, C19.1, L2.2, U4.15 (VDDTX), U4.19 (VDDRX), U4.20 (VDDPLL), U4.25 (VDDOSC), U4.28 (VDD); also elsewhere on the board

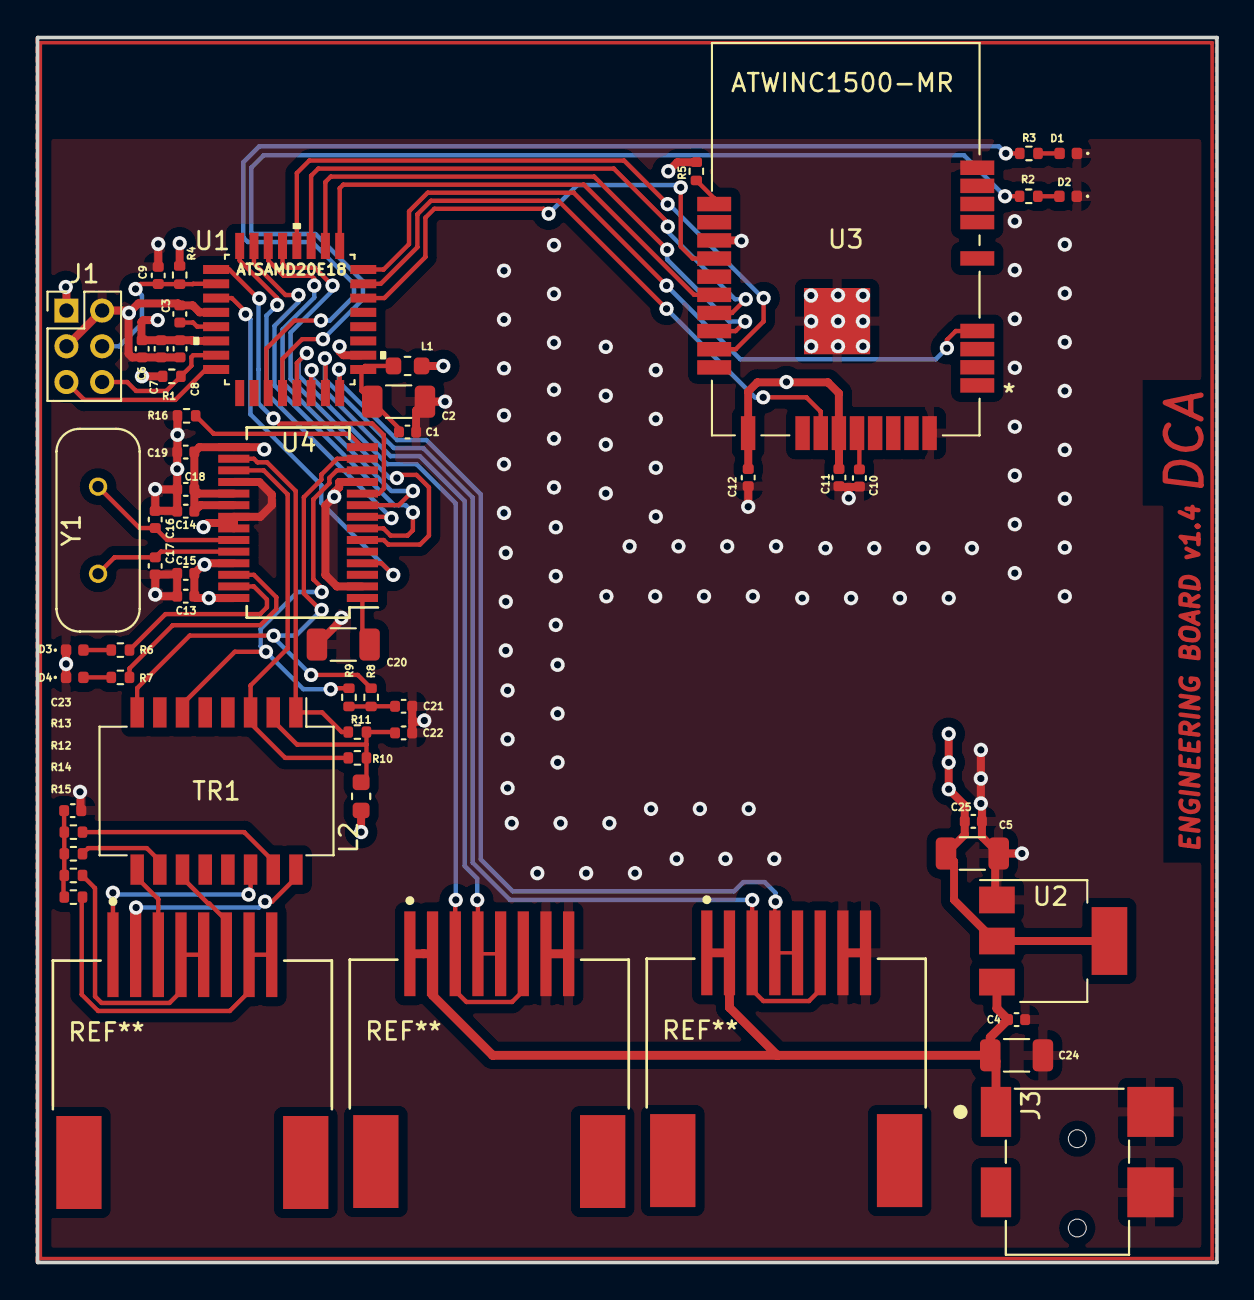
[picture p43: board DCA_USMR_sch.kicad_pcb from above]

Board: 4 copper layers, 66.0 x 68.6 mm, 55 parts (0 on the bottom side), 44 nets.

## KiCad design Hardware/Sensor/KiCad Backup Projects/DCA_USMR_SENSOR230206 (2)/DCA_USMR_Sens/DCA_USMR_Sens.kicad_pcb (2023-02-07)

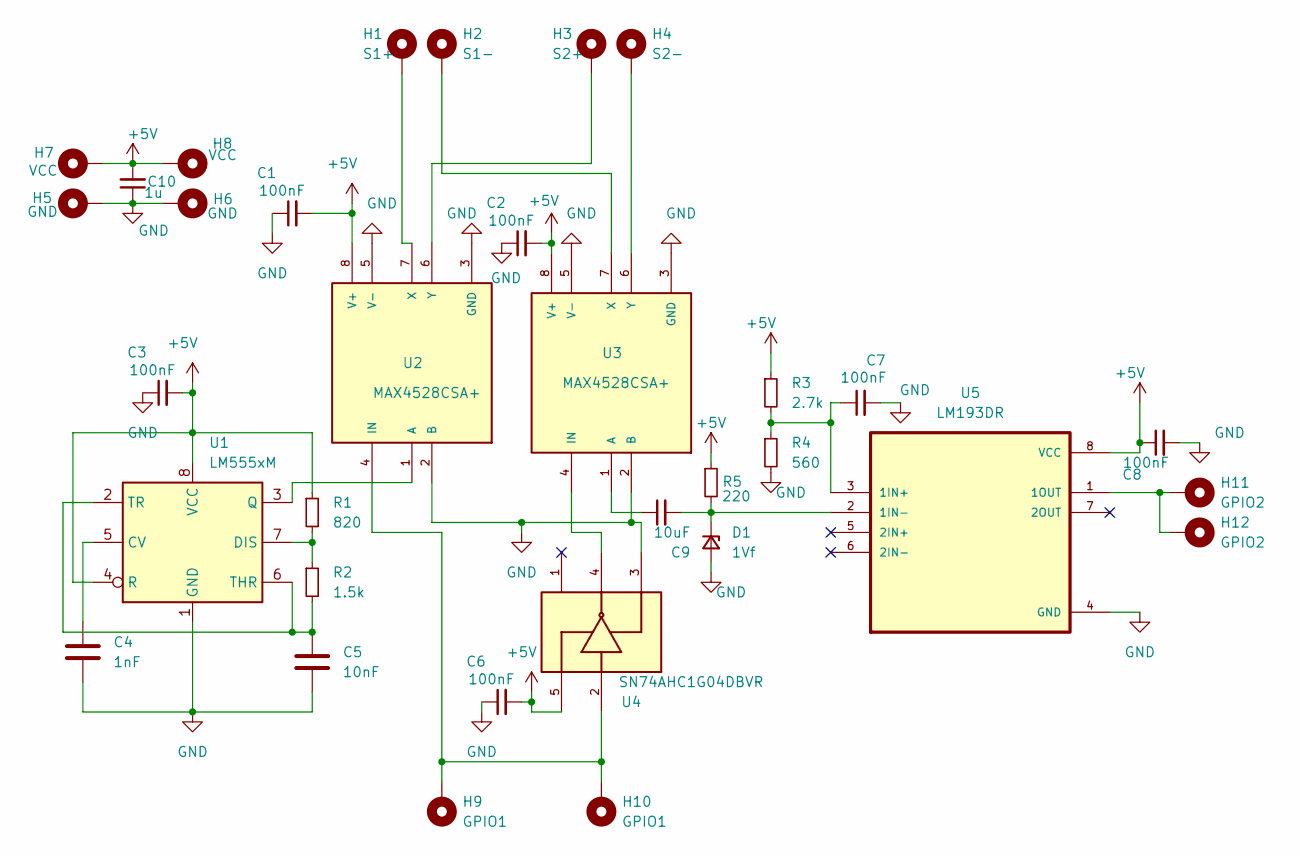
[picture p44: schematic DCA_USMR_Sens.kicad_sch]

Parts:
C1, C2, C3, C6, C7, C8: 100nF; C_0402_1005Metric
C4: 1nF; C_0402_1005Metric
C5: 10nF; C_0402_1005Metric
C9: 10uF; C_0402_1005Metric
C10: 1u; C_0603_1608Metric
D1: 1Vf; DIOAD835W50L444D203
H1: S1+; Pin_D0.7mm_L6.5mm_W1.8mm_FlatFork
H2: S1-; Pin_D0.7mm_L6.5mm_W1.8mm_FlatFork
H3: S2+; Pin_D0.7mm_L6.5mm_W1.8mm_FlatFork
H4: S2-; Pin_D0.7mm_L6.5mm_W1.8mm_FlatFork
H5, H6: GND; Pin_D0.7mm_L6.5mm_W1.8mm_FlatFork
H7, H8: VCC; Pin_D0.7mm_L6.5mm_W1.8mm_FlatFork
H9, H10: GPIO1; Pin_D0.7mm_L6.5mm_W1.8mm_FlatFork
H11, H12: GPIO2; Pin_D0.7mm_L6.5mm_W1.8mm_FlatFork
R1: 820; R_0402_1005Metric
R2: 1.5k; R_0402_1005Metric
R3: 2.7k; R_0402_1005Metric
R4: 560; R_0402_1005Metric
R5: 220; R_0402_1005Metric
U1: LM555xM; SOIC-8_3.9x4.9mm_P1.27mm
U2, U3: MAX4528CSA+; SOIC127P600X175-8N
U4: SN74AHC1G04DBVR; SOT95P280X145-5N; PARTREV AD
U5: LM193DR; SOIC127P599X175-8N

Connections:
+5V: C1.2, C2.2, C3.2, C6.2, C8.1, C10.2, H7.1, H8.1, R1.1, R3.1, R5.1, U1.4 (R), U1.8 (VCC), U2.8 (V+), U3.8 (V+), U4.5, U5.8 (VCC)
GND: C1.1, C2.1, C3.1, C4.2, C5.2, C6.1, C7.2, C8.2, C10.1, D1.2 (A), H5.1, H6.1, R4.2, U1.1 (GND), U2.2 (B), U2.3 (GND), U2.5 (V-), U3.2 (B), U3.3 (GND), U3.5 (V-), U4.3, U5.4 (GND)
unnamed: C4.1, U1.5 (CV)
unnamed: C5.1, R2.2, U1.2 (TR), U1.6 (THR)
unnamed: C7.1, R3.2, R4.1, U5.3 (1IN+)
unnamed: C9.1, U3.1 (A)
unnamed: C9.2, D1.1 (K), R5.2, U5.2 (1IN-)
unnamed: R1.2, R2.1, U1.7 (DIS)
unnamed: U1.3 (Q), U2.1 (A)
unnamed: H9.1, H10.1, U2.4 (IN), U4.2
unnamed: H3.1, U2.6 (Y)
unnamed: H1.1, U2.7 (X)
unnamed: U3.4 (IN), U4.4
unnamed: H4.1, U3.6 (Y)
unnamed: H2.1, U3.7 (X)
unnamed: H11.1, H12.1, U5.1 (1OUT)

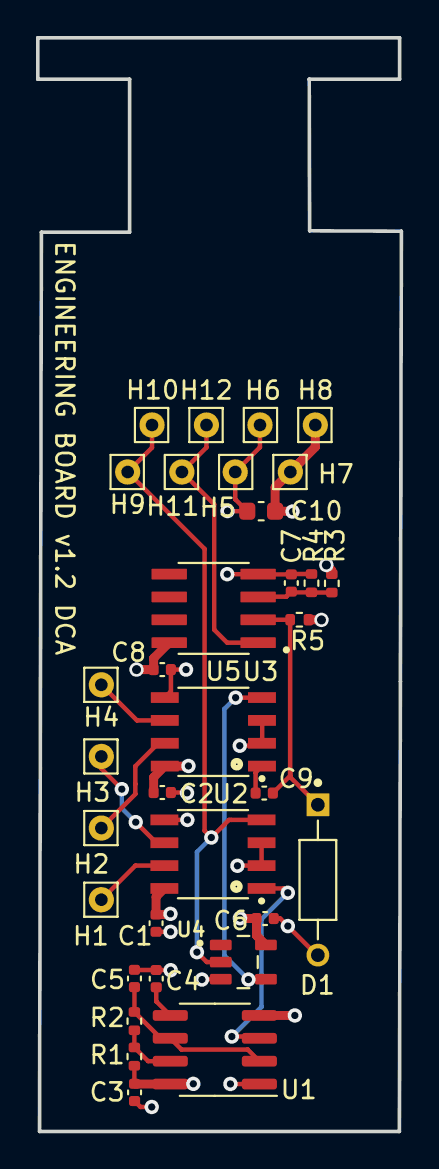
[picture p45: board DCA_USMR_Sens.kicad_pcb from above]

Board: 4 copper layers, 20.2 x 60.8 mm, 33 parts (0 on the bottom side), 16 nets.

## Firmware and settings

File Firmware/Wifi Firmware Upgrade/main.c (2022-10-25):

/**
 *
 * \file
 *
 * \brief WINC1500 Firmware Update
 *
 * Copyright (c) 2016-2018 Microchip Technology Inc. and its subsidiaries.
 *
 * \asf_license_start
 *
 * \page License
 *
 * Subject to your compliance with these terms, you may use Microchip
 * software and any derivatives exclusively with Microchip products.
 * It is your responsibility to comply with third party license terms applicable
 * to your use of third party software (including open source software) that
 * may accompany Microchip software.
 *
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
 * \asf_license_stop
 *
 */

/** \mainpage
 * \section intro Introduction
 * This empty project is a placeholder for the tools to use to perform the
 * following actions:
 * - WINC1500 firmware update
 * - WINC1500 root certificate update
 *
 * It can be used with the following hardware:
 * - the SAMG53 Xplained Pro.
 * - the SAMG55 Xplained Pro.
 * - the SAMD21 Xplained Pro.
 * - the SAMW25 Xplained Pro.
 * - the WINC1500 must be connected to EXT1.
 *
 * For a more information about WINC1500 update please refer to the following document
 * available under the doc folder:
 * - Atmel-AN004-Firmware-Update-Procedure-for-WINC1500-WiFi-Module-using-SAM-Xplained-Pro.pdf
 *
 * \section files Main Files
 * - samXXX_xplained_pro_firmware_update.bat : script to perform firmware update.
 * - samXXX_xplained_pro_certificate_update.bat : script to perform root certificate
 * update.
 *
 * \section contactinfo Contact Information
 * For further information, visit
 * <A href="http://www.microchip.com">Microchip</A>.\n
 */

#include "asf.h"

int main(void)
{
	while (1) {
	}
	return 0;
}

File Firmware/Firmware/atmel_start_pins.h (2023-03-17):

/*
 * Code generated from Atmel Start.
 *
 * This file will be overwritten when reconfiguring your Atmel Start project.
 * Please copy examples or other code you want to keep to a separate file
 * to avoid losing it when reconfiguring.
 */
#ifndef ATMEL_START_PINS_H_INCLUDED
#define ATMEL_START_PINS_H_INCLUDED

#include <hal_gpio.h>

// SAMD20 has 8 pin functions

#define GPIO_PIN_FUNCTION_A 0
#define GPIO_PIN_FUNCTION_B 1
#define GPIO_PIN_FUNCTION_C 2
#define GPIO_PIN_FUNCTION_D 3
#define GPIO_PIN_FUNCTION_E 4
#define GPIO_PIN_FUNCTION_F 5
#define GPIO_PIN_FUNCTION_G 6
#define GPIO_PIN_FUNCTION_H 7

#define LED_GREEN GPIO(GPIO_PORTA, 2)
#define LED_RED GPIO(GPIO_PORTA, 3)
#define SENSOR1_IN GPIO(GPIO_PORTA, 4)
#define SENSOR1_OUT GPIO(GPIO_PORTA, 5)
#define SENSOR2_IN GPIO(GPIO_PORTA, 6)
#define SENSOR2_OUT GPIO(GPIO_PORTA, 7)
#define WIRELESS_IRQn GPIO(GPIO_PORTA, 11)
#define WIRELESS_EN GPIO(GPIO_PORTA, 14)
#define WIRELESS_RESETn GPIO(GPIO_PORTA, 15)
#define WIRELESS_MOSI GPIO(GPIO_PORTA, 16)
#define WIRELESS_MISO GPIO(GPIO_PORTA, 17)
#define WIRELESS_CSn GPIO(GPIO_PORTA, 18)
#define WIRELESS_SCK GPIO(GPIO_PORTA, 19)
#define ETHERNET_MISO GPIO(GPIO_PORTA, 22)
#define ETHERNET_CS GPIO(GPIO_PORTA, 23)
#define ETHERNET_MOSI GPIO(GPIO_PORTA, 24)
#define ETHERNET_SCK GPIO(GPIO_PORTA, 25)
#define ETHERNET_RESET GPIO(GPIO_PORTA, 27)
#define ETHERNET_IRQ GPIO(GPIO_PORTA, 28)

#endif // ATMEL_START_PINS_H_INCLUDED

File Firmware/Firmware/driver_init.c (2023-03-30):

/*
 * Code generated from Atmel Start.
 *
 * This file will be overwritten when reconfiguring your Atmel Start project.
 * Please copy examples or other code you want to keep to a separate file
 * to avoid losing it when reconfiguring.
 */

#include "driver_init.h"
#include <peripheral_clk_config.h>
#include <utils.h>
#include <hal_init.h>
#include <hpl_gclk_base.h>
#include <hpl_pm_base.h>

struct spi_m_sync_descriptor WIRELESS_SPI;
struct spi_m_sync_descriptor ETHERNET_SPI;
struct timer_descriptor      TIMER_0;
struct timer_descriptor      SAMPLE_TIMER;
struct timer_descriptor      TICK_TIMER;

struct flash_descriptor FLASH_0;

struct wdt_descriptor WDT_0;

void EXTERNAL_IRQ_0_init(void)
{
	_gclk_enable_channel(EIC_GCLK_ID, CONF_GCLK_EIC_SRC);

	// Set pin direction to input
	gpio_set_pin_direction(SENSOR1_IN, GPIO_DIRECTION_IN);

	gpio_set_pin_pull_mode(SENSOR1_IN,
	                       // <y> Pull configuration
	                       // <id> pad_pull_config
	                       // <GPIO_PULL_OFF"> Off
	                       // <GPIO_PULL_UP"> Pull-up
	                       // <GPIO_PULL_DOWN"> Pull-down
	                       GPIO_PULL_OFF);

	gpio_set_pin_function(SENSOR1_IN, PINMUX_PA04A_EIC_EXTINT4);

	// Set pin direction to input
	gpio_set_pin_direction(SENSOR2_IN, GPIO_DIRECTION_IN);

	gpio_set_pin_pull_mode(SENSOR2_IN,
	                       // <y> Pull configuration
	                       // <id> pad_pull_config
	                       // <GPIO_PULL_OFF"> Off
	                       // <GPIO_PULL_UP"> Pull-up
	                       // <GPIO_PULL_DOWN"> Pull-down
	                       GPIO_PULL_OFF);

	gpio_set_pin_function(SENSOR2_IN, PINMUX_PA06A_EIC_EXTINT6);

	// Set pin direction to input
	gpio_set_pin_direction(ETHERNET_IRQ, GPIO_DIRECTION_IN);

	gpio_set_pin_pull_mode(ETHERNET_IRQ,
	                       // <y> Pull configuration
	                       // <id> pad_pull_config
	                       // <GPIO_PULL_OFF"> Off
	                       // <GPIO_PULL_UP"> Pull-up
	                       // <GPIO_PULL_DOWN"> Pull-down
	                       GPIO_PULL_OFF);

	gpio_set_pin_function(ETHERNET_IRQ, PINMUX_PA28A_EIC_EXTINT8);

	// Set pin direction to input
	gpio_set_pin_direction(WIRELESS_IRQn, GPIO_DIRECTION_IN);

	gpio_set_pin_pull_mode(WIRELESS_IRQn,
	                       // <y> Pull configuration
	                       // <id> pad_pull_config
	                       // <GPIO_PULL_OFF"> Off
	                       // <GPIO_PULL_UP"> Pull-up
	                       // <GPIO_PULL_DOWN"> Pull-down
	                       GPIO_PULL_OFF);

	gpio_set_pin_function(WIRELESS_IRQn, PINMUX_PA11A_EIC_EXTINT11);

	ext_irq_init();
}

void FLASH_0_CLOCK_init(void)
{

	_pm_enable_bus_clock(PM_BUS_APBB, NVMCTRL);
}

void FLASH_0_init(void)
{
	FLASH_0_CLOCK_init();
	flash_init(&FLASH_0, NVMCTRL);
}

void WIRELESS_SPI_PORT_init(void)
{

	gpio_set_pin_level(WIRELESS_MOSI,
	                   // <y> Initial level
	                   // <id> pad_initial_level
	                   // <false"> Low
	                   // <true"> High
	                   false);

	// Set pin direction to output
	gpio_set_pin_direction(WIRELESS_MOSI, GPIO_DIRECTION_OUT);

	gpio_set_pin_function(WIRELESS_MOSI, PINMUX_PA16C_SERCOM1_PAD0);

	// Set pin direction to input
	gpio_set_pin_direction(WIRELESS_MISO, GPIO_DIRECTION_IN);

	gpio_set_pin_pull_mode(WIRELESS_MISO,
	                       // <y> Pull configuration
	                       // <id> pad_pull_config
	                       // <GPIO_PULL_OFF"> Off
	                       // <GPIO_PULL_UP"> Pull-up
	                       // <GPIO_PULL_DOWN"> Pull-down
	                       GPIO_PULL_UP);

	gpio_set_pin_function(WIRELESS_MISO, PINMUX_PA17C_SERCOM1_PAD1);

	gpio_set_pin_level(WIRELESS_SCK,
	                   // <y> Initial level
	                   // <id> pad_initial_level
	                   // <false"> Low
	                   // <true"> High
	                   true);

	// Set pin direction to output
	gpio_set_pin_direction(WIRELESS_SCK, GPIO_DIRECTION_OUT);

	gpio_set_pin_function(WIRELESS_SCK, PINMUX_PA19C_SERCOM1_PAD3);
}

void WIRELESS_SPI_CLOCK_init(void)
{
	_pm_enable_bus_clock(PM_BUS_APBC, SERCOM1);
	_gclk_enable_channel(SERCOM1_GCLK_ID_CORE, CONF_GCLK_SERCOM1_CORE_SRC);
}

void WIRELESS_SPI_init(void)
{
	WIRELESS_SPI_CLOCK_init();
	spi_m_sync_init(&WIRELESS_SPI, SERCOM1);
	WIRELESS_SPI_PORT_init();
}

void ETHERNET_SPI_PORT_init(void)
{

	// Set pin direction to input
	gpio_set_pin_direction(ETHERNET_MISO, GPIO_DIRECTION_IN);

	gpio_set_pin_pull_mode(ETHERNET_MISO,
	                       // <y> Pull configuration
	                       // <id> pad_pull_config
	                       // <GPIO_PULL_OFF"> Off
	                       // <GPIO_PULL_UP"> Pull-up
	                       // <GPIO_PULL_DOWN"> Pull-down
	                       GPIO_PULL_OFF);

	gpio_set_pin_function(ETHERNET_MISO, PINMUX_PA22C_SERCOM3_PAD0);

	gpio_set_pin_level(ETHERNET_MOSI,
	                   // <y> Initial level
	                   // <id> pad_initial_level
	                   // <false"> Low
	                   // <true"> High
	                   false);

	// Set pin direction to output
	gpio_set_pin_direction(ETHERNET_MOSI, GPIO_DIRECTION_OUT);

	gpio_set_pin_function(ETHERNET_MOSI, PINMUX_PA24C_SERCOM3_PAD2);

	gpio_set_pin_level(ETHERNET_SCK,
	                   // <y> Initial level
	                   // <id> pad_initial_level
	                   // <false"> Low
	                   // <true"> High
	                   false);

	// Set pin direction to output
	gpio_set_pin_direction(ETHERNET_SCK, GPIO_DIRECTION_OUT);

	gpio_set_pin_function(ETHERNET_SCK, PINMUX_PA25C_SERCOM3_PAD3);
}

void ETHERNET_SPI_CLOCK_init(void)
{
	_pm_enable_bus_clock(PM_BUS_APBC, SERCOM3);
	_gclk_enable_channel(SERCOM3_GCLK_ID_CORE, CONF_GCLK_SERCOM3_CORE_SRC);
}

void ETHERNET_SPI_init(void)
{
	ETHERNET_SPI_CLOCK_init();
	spi_m_sync_init(&ETHERNET_SPI, SERCOM3);
	ETHERNET_SPI_PORT_init();
}

void delay_driver_init(void)
{
	delay_init(SysTick);
}

/**
 * \brief Timer initialization function
 *
 * Enables Timer peripheral, clocks and initializes Timer driver
 */
static void TIMER_0_init(void)
{
	_pm_enable_bus_clock(PM_BUS_APBC, TC0);
	_gclk_enable_channel(TC0_GCLK_ID, CONF_GCLK_TC0_SRC);

	timer_init(&TIMER_0, TC0, _tc_get_timer());
}

/**
 * \brief Timer initialization function
 *
 * Enables Timer peripheral, clocks and initializes Timer driver
 */
static void SAMPLE_TIMER_init(void)
{
	_pm_enable_bus_clock(PM_BUS_APBC, TC2);
	_gclk_enable_channel(TC2_GCLK_ID, CONF_GCLK_TC2_SRC);

	timer_init(&SAMPLE_TIMER, TC2, _tc_get_timer());
}

/**
 * \brief Timer initialization function
 *
 * Enables Timer peripheral, clocks and initializes Timer driver
 */
static void TICK_TIMER_init(void)
{
	_pm_enable_bus_clock(PM_BUS_APBC, TC4);
	_gclk_enable_channel(TC4_GCLK_ID, CONF_GCLK_TC4_SRC);

	timer_init(&TICK_TIMER, TC4, _tc_get_timer());
}
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

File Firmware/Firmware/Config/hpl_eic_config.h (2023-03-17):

/* Auto-generated config file hpl_eic_config.h */
#ifndef HPL_EIC_CONFIG_H
#define HPL_EIC_CONFIG_H

// <<< Use Configuration Wizard in Context Menu >>>

// <h> Non-Maskable Interrupt Control
// <q> Non-Maskable Interrupt Filter Enable
// <i> Indicates whether the mon-maskable interrupt filter is enabled or not
// <id> eic_arch_nmifilten
#ifndef CONF_EIC_NMIFILTEN
#define CONF_EIC_NMIFILTEN 0
#endif

// <y> Non-Maskable Interrupt Sense
// <EIC_NMICTRL_NMISENSE_NONE_Val"> No detection
// <EIC_NMICTRL_NMISENSE_RISE_Val"> Rising-edge detection
// <EIC_NMICTRL_NMISENSE_FALL_Val"> Falling-edge detection
// <EIC_NMICTRL_NMISENSE_BOTH_Val"> Both-edges detection
// <EIC_NMICTRL_NMISENSE_HIGH_Val"> High-level detection
// <EIC_NMICTRL_NMISENSE_LOW_Val"> Low-level detection
// <i> This defines non-maskable interrupt sense
// <id> eic_arch_nmisense
#ifndef CONF_EIC_NMISENSE
#define CONF_EIC_NMISENSE EIC_NMICTRL_NMISENSE_NONE_Val
#endif
// </h>

// <e> Interrupt 0 Settings
// <id> eic_arch_enable_irq_setting0
#ifndef CONF_EIC_ENABLE_IRQ_SETTING0
#define CONF_EIC_ENABLE_IRQ_SETTING0 0
#endif

// <q> External Interrupt 0 Event Output Enable
// <i> Indicates whether the external interrupt 0 event output is enabled or not
// <id> eic_arch_extinteo0
#ifndef CONF_EIC_EXTINTEO0
#define CONF_EIC_EXTINTEO0 0
#endif

// <q> External Interrupt 0 Wake-up Enable
// <i> Indicates whether the external interrupt 0 wake-up is enabled or not
// <id> eic_arch_wakeupen0
#ifndef CONF_EIC_WAKEUPEN0
#define CONF_EIC_WAKEUPEN0 0
#endif

// <q> External Interrupt 0 Filter Enable
// <i> Indicates whether the external interrupt 0 filter is enabled or not
// <id> eic_arch_filten0
#ifndef CONF_EIC_FILTEN0
#define CONF_EIC_FILTEN0 0
#endif

// <y> Input 0 Sense Configuration
// <EIC_NMICTRL_NMISENSE_NONE_Val"> No detection
// <EIC_NMICTRL_NMISENSE_RISE_Val"> Rising-edge detection
// <EIC_NMICTRL_NMISENSE_FALL_Val"> Falling-edge detection
// <EIC_NMICTRL_NMISENSE_BOTH_Val"> Both-edges detection
// <EIC_NMICTRL_NMISENSE_HIGH_Val"> High-level detection
// <EIC_NMICTRL_NMISENSE_LOW_Val"> Low-level detection
// <i> This defines input sense trigger
// <id> eic_arch_sense0
#ifndef CONF_EIC_SENSE0
#define CONF_EIC_SENSE0 EIC_NMICTRL_NMISENSE_NONE_Val
#endif
// </e>

// <e> Interrupt 1 Settings
// <id> eic_arch_enable_irq_setting1
#ifndef CONF_EIC_ENABLE_IRQ_SETTING1
#define CONF_EIC_ENABLE_IRQ_SETTING1 0
#endif

// <q> External Interrupt 1 Event Output Enable
// <i> Indicates whether the external interrupt 1 event output is enabled or not
// <id> eic_arch_extinteo1
#ifndef CONF_EIC_EXTINTEO1
#define CONF_EIC_EXTINTEO1 0
#endif

// <q> External Interrupt 1 Wake-up Enable
// <i> Indicates whether the external interrupt 1 wake-up is enabled or not
// <id> eic_arch_wakeupen1
#ifndef CONF_EIC_WAKEUPEN1
#define CONF_EIC_WAKEUPEN1 0
#endif

// <q> External Interrupt 1 Filter Enable
// <i> Indicates whether the external interrupt 1 filter is enabled or not
// <id> eic_arch_filten1
#ifndef CONF_EIC_FILTEN1
#define CONF_EIC_FILTEN1 0
#endif

// <y> Input 1 Sense Configuration
// <EIC_NMICTRL_NMISENSE_NONE_Val"> No detection
// <EIC_NMICTRL_NMISENSE_RISE_Val"> Rising-edge detection
// <EIC_NMICTRL_NMISENSE_FALL_Val"> Falling-edge detection
// <EIC_NMICTRL_NMISENSE_BOTH_Val"> Both-edges detection
// <EIC_NMICTRL_NMISENSE_HIGH_Val"> High-level detection
// <EIC_NMICTRL_NMISENSE_LOW_Val"> Low-level detection
// <i> This defines input sense trigger
// <id> eic_arch_sense1
#ifndef CONF_EIC_SENSE1
#define CONF_EIC_SENSE1 EIC_NMICTRL_NMISENSE_NONE_Val
#endif
// </e>

// <e> Interrupt 2 Settings
// <id> eic_arch_enable_irq_setting2
#ifndef CONF_EIC_ENABLE_IRQ_SETTING2
#define CONF_EIC_ENABLE_IRQ_SETTING2 0
#endif

// <q> External Interrupt 2 Event Output Enable
// <i> Indicates whether the external interrupt 2 event output is enabled or not
// <id> eic_arch_extinteo2
#ifndef CONF_EIC_EXTINTEO2
#define CONF_EIC_EXTINTEO2 0
#endif

// <q> External Interrupt 2 Wake-up Enable
// <i> Indicates whether the external interrupt 2 wake-up is enabled or not
// <id> eic_arch_wakeupen2
#ifndef CONF_EIC_WAKEUPEN2
#define CONF_EIC_WAKEUPEN2 0
#endif

// <q> External Interrupt 2 Filter Enable
// <i> Indicates whether the external interrupt 2 filter is enabled or not
// <id> eic_arch_filten2
#ifndef CONF_EIC_FILTEN2
#define CONF_EIC_FILTEN2 0
#endif

// <y> Input 2 Sense Configuration
// <EIC_NMICTRL_NMISENSE_NONE_Val"> No detection
// <EIC_NMICTRL_NMISENSE_RISE_Val"> Rising-edge detection
// <EIC_NMICTRL_NMISENSE_FALL_Val"> Falling-edge detection
// <EIC_NMICTRL_NMISENSE_BOTH_Val"> Both-edges detection
// <EIC_NMICTRL_NMISENSE_HIGH_Val"> High-level detection
// <EIC_NMICTRL_NMISENSE_LOW_Val"> Low-level detection
// <i> This defines input sense trigger
// <id> eic_arch_sense2
#ifndef CONF_EIC_SENSE2
#define CONF_EIC_SENSE2 EIC_NMICTRL_NMISENSE_NONE_Val
#endif
// </e>

// <e> Interrupt 3 Settings
// <id> eic_arch_enable_irq_setting3
#ifndef CONF_EIC_ENABLE_IRQ_SETTING3
#define CONF_EIC_ENABLE_IRQ_SETTING3 0
#endif

// <q> External Interrupt 3 Event Output Enable
// <i> Indicates whether the external interrupt 3 event output is enabled or not
// <id> eic_arch_extinteo3
#ifndef CONF_EIC_EXTINTEO3
#define CONF_EIC_EXTINTEO3 0
#endif

// <q> External Interrupt 3 Wake-up Enable
// <i> Indicates whether the external interrupt 3 wake-up is enabled or not
// <id> eic_arch_wakeupen3
#ifndef CONF_EIC_WAKEUPEN3
#define CONF_EIC_WAKEUPEN3 0
#endif

// <q> External Interrupt 3 Filter Enable
// <i> Indicates whether the external interrupt 3 filter is enabled or not
// <id> eic_arch_filten3
#ifndef CONF_EIC_FILTEN3
#define CONF_EIC_FILTEN3 0
#endif

// <y> Input 3 Sense Configuration
// <EIC_NMICTRL_NMISENSE_NONE_Val"> No detection
// <EIC_NMICTRL_NMISENSE_RISE_Val"> Rising-edge detection
// <EIC_NMICTRL_NMISENSE_FALL_Val"> Falling-edge detection
// <EIC_NMICTRL_NMISENSE_BOTH_Val"> Both-edges detection
// <EIC_NMICTRL_NMISENSE_HIGH_Val"> High-level detection
// <EIC_NMICTRL_NMISENSE_LOW_Val"> Low-level detection
// <i> This defines input sense trigger
// <id> eic_arch_sense3
#ifndef CONF_EIC_SENSE3
#define CONF_EIC_SENSE3 EIC_NMICTRL_NMISENSE_NONE_Val
#endif
// </e>

// <e> Interrupt 4 Settings
// <id> eic_arch_enable_irq_setting4
#ifndef CONF_EIC_ENABLE_IRQ_SETTING4
#define CONF_EIC_ENABLE_IRQ_SETTING4 0
#endif

// <q> External Interrupt 4 Event Output Enable
// <i> Indicates whether the external interrupt 4 event output is enabled or not
// <id> eic_arch_extinteo4
#ifndef CONF_EIC_EXTINTEO4
#define CONF_EIC_EXTINTEO4 0
#endif

// <q> External Interrupt 4 Wake-up Enable
// <i> Indicates whether the external interrupt 4 wake-up is enabled or not
// <id> eic_arch_wakeupen4
#ifndef CONF_EIC_WAKEUPEN4
#define CONF_EIC_WAKEUPEN4 0
#endif

// <q> External Interrupt 4 Filter Enable
// <i> Indicates whether the external interrupt 4 filter is enabled or not
// <id> eic_arch_filten4
#ifndef CONF_EIC_FILTEN4
#define CONF_EIC_FILTEN4 0
#endif
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

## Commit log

2022-09-28 Add files via upload
    SAMD21 Dev board guide
    SAMD21 WINC with Dev board guide.
2022-10-29 Refactor repository.
    [BurnDown.xlsx, Ethernet.kicad_sch, MC.kicad_sch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]
2022-11-01 Revision 2
    Fixes based after sponsor interview.
    [MC.kicad_sch]
2022-11-02 Update and rename circuit_parts.txt to circuit_parts.md
2022-11-03 Revision 3
    Revisions made after meeting with sponsor.
    [Ethernet.kicad_sch, MC.kicad_sch, WINC.kicad_sch]
2022-11-04 Firmware flowchart v1.0
2022-11-09 Reformated Firmware structure Built from Atmel Start
    All GPIO pins declared
    Added Watchdog
    Added Timer
    Added Wifi
    Added Ethernet
    Added Main App Program Loop
    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
2022-11-10 PCB_Revision_1
    Before sponsor changes
    [DCA_USMR_sch.kicad_pcb]
2022-11-10 Revision 4
    Merged into 1 sheet after meeting with sponsor
    [DCA_USMR_sch.kicad_sch]
2022-11-10 PCB Captures v1.0
2022-11-10 Schematic PDF
2022-11-12 Revision v1.1
    Main PCB changes, Moved power to bottom right. Made power rails 0.5mil.
    [DCA_USMR_sch.kicad_pcb, Ethernet_C.kicad_sch, WINC_C.kicad_sch]
2022-11-16 Updated Repo organization. Board Schematic, Pcb, and Gerbers all updated. First set of Engineering boards ordered on 221115
    [BurnDown.xlsx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]
2022-11-17 Sprint 2 Week 4 Report
    PCB ordered, sensor module completed
2022-11-18 First version of Flow Sensor module
    [MAX4528CPA_.step]
2022-11-18 Fixed schematic issue. Inverter was going to input instead of control.
    [DCA_USMR_SENSOR.kicad_pcb, DCA_USMR_SENSOR.kicad_sch]
2022-12-08 Block Diagram for Sensor
2023-02-02 Sensor Rev1.1
    Rev1.1
    [DCA_USMR_Sens.kicad_pcb, DCA_USMR_Sens.kicad_sch]
2023-02-03 Revision 2
    v2.0.1
    [DCA_USMR_Sens.kicad_pcb, DCA_USMR_Sens.kicad_sch]
2023-02-06 Cleanup directory location
    [DCA_USMR_Sens.kicad_pcb, DCA_USMR_Sens.kicad_sch]
2023-02-06 First build of backend server. Amazon Linux 2.
    [config.rst.txt]
2023-02-06 Newest version. Dns, Socket, and TCP state machines. Can connect to hw.darmorgamz.ca and send/recieve data.
2023-02-06 Newest board spin. Fixed Wifi, and ethernet SPI ports. Added Sensor connectors with digital In/Outs
    [DCA_USMR_sch.kicad_pcb, DCA_USMR_sch.kicad_sch, WINC_C.kicad_sch]
2023-02-07 Sensor Updates. Boards Ordered.
    [DCA_USMR_Sens-B_Courtyard.gbr, DCA_USMR_Sens-B_Cu.gbl, DCA_USMR_Sens-B_Mask.gbs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]
2023-03-08 Frontend of Server facelift.
    [DCA_USMR_sch.kicad_pcb, DCA_USMR_sch.kicad_sch, Ethernet_C.kicad_sch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]
2023-03-09 Create Enclosure
2023-03-17 Repo cleanup
    [DCA_Sensor_Enclosure_V0.0.1.stl, DCA_Sensor_Enclosure_V0.0.2.stl, DCA_Sensor_Enclosure_V0.1.1.stl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]
2023-03-17 Current Server version
    [config.rst.txt]
2023-03-17 Current client version
2023-03-17 Current Backend Version
    [config.rst.txt]
2023-03-17 Current Firmware version
2023-03-23 Added Functionality to Reset Password button. Apache on the server removed redirect. You must access /index2.php to see client. / is used for Hw root because im lazy. Data on backend is now limited t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
2023-03-30 Reading buffer with rolling 1sec average using 32bit tick timer. two buffers are used, one will be reading, one with me writing.
2023-03-30 First point in averaging algo isn't a time difference, it's the current ticks. This causes the first data point to be higher than expected.
2023-03-30 Tests for Hardware Timers
2023-04-12 Changes made for Sensor EXT. Sensor comparator is so fast that the main program loop get blocked. Collects 128 Avg points per second and then turns off EXT. EXT turned back on every 1sec callback.
2023-04-12 Removed phpMyAdmin from Backend directory.
    [config.rst.txt]
2023-04-12 Un needed directory.
    [config.rst.txt]
2023-04-12 Moved to documents directory
    [BurnDown.xlsx]

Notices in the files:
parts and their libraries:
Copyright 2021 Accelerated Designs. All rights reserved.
